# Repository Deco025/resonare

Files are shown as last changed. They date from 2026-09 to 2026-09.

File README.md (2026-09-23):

# Resonare

**120 W LCC-S 谐振式无线充电：发射板 + 接收板**





> *Resonare* (Latin: “to resound”) is an open-source 120 W wireless charger built on an LCC-S resonant
> topology. A 24 V transmitter drives a full bridge into an LCC compensation network; the receiver rectifies,
> steps down with a synchronous buck and charges a supercapacitor bank through an ideal-diode stage.
> Both boards are 4-layer KiCad 10 designs with complete fabrication outputs.

| 发射板 TX（82 × 60 mm） | 接收板 RX（75 × 60 mm） |
|---|---|
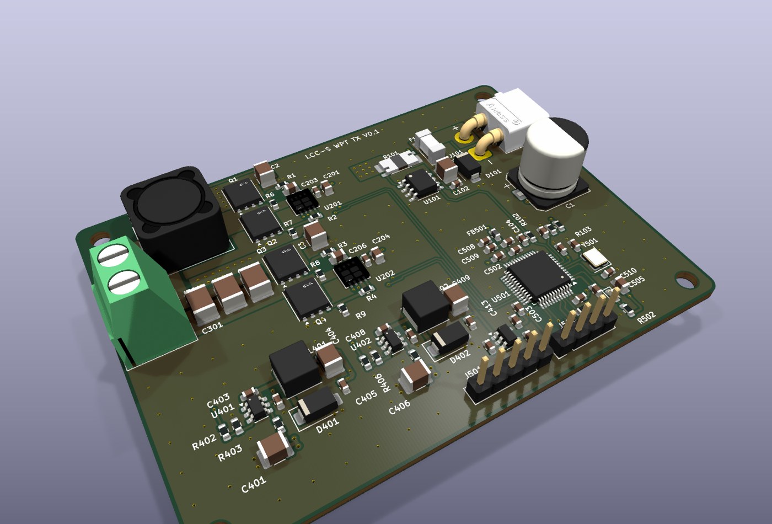
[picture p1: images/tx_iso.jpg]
TX
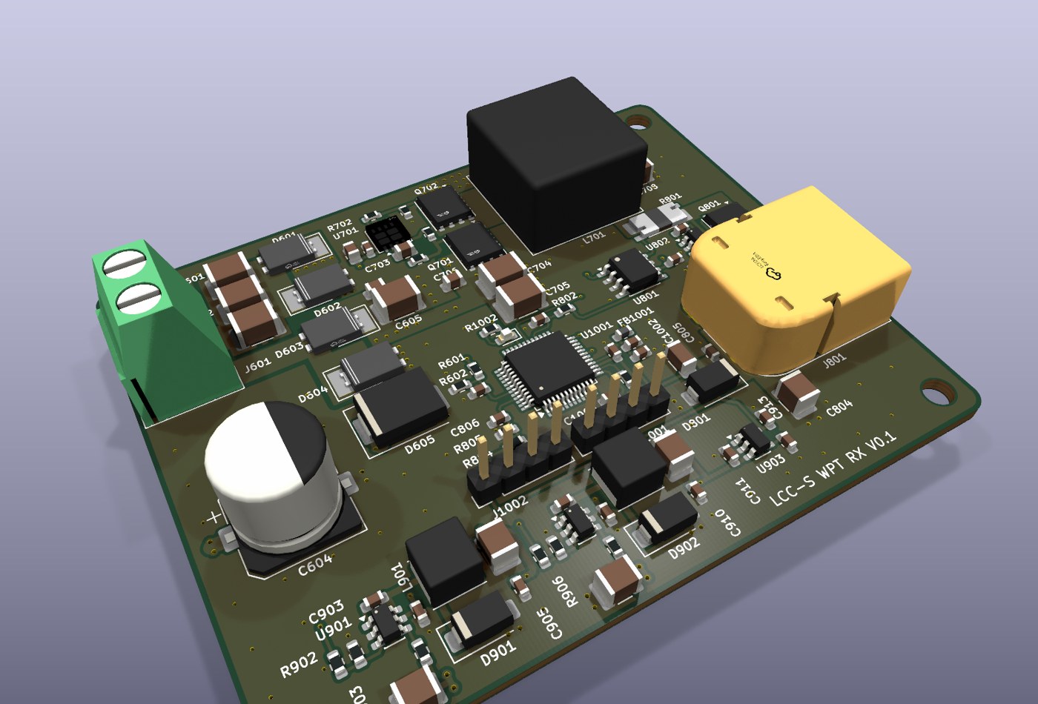
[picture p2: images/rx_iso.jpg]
RX
|  |  |

### PCB 走线

| | 顶层 F.Cu | 底层 B.Cu（从背面看） |
|---|---|---|
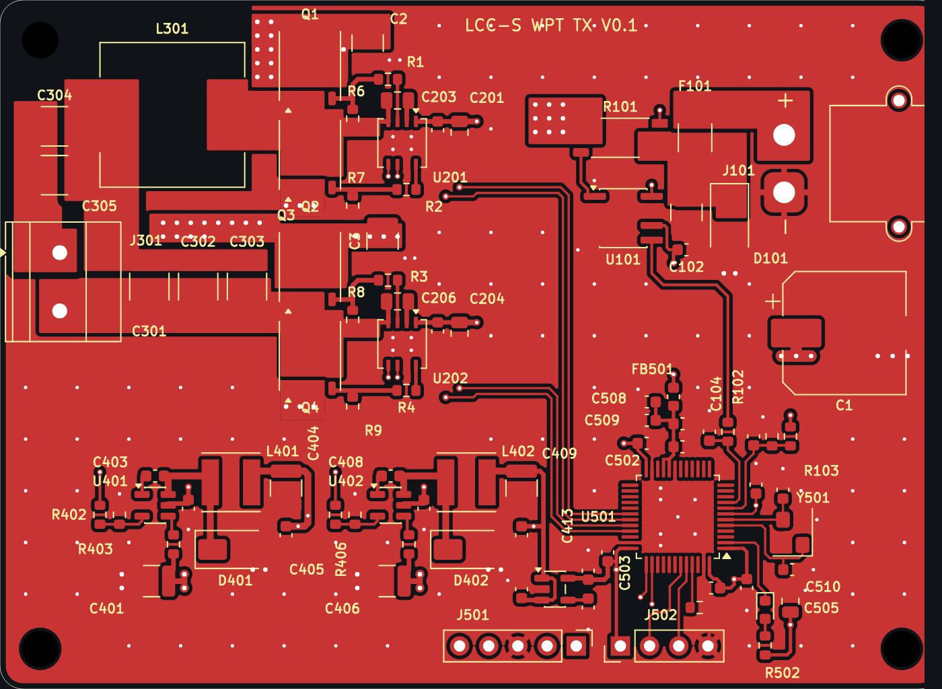
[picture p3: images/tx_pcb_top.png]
TX top copper
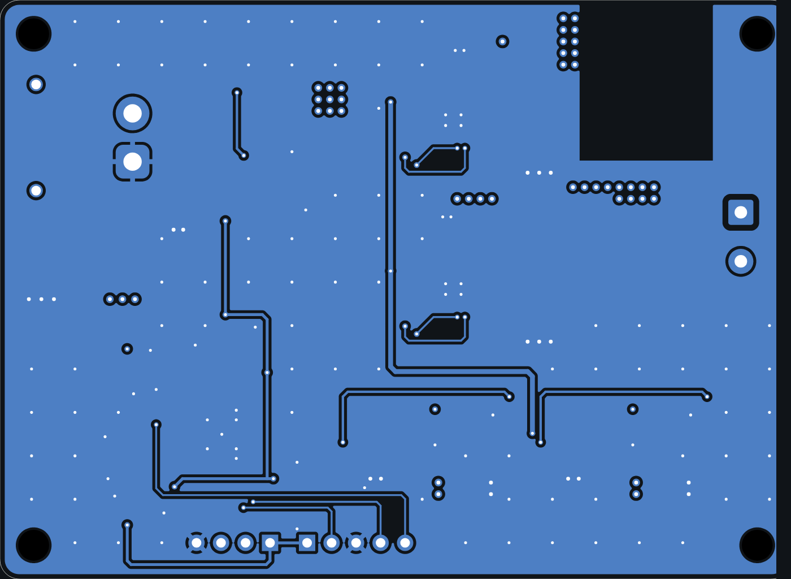
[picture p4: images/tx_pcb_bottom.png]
TX bottom copper
| **发射板 TX** |  |  |
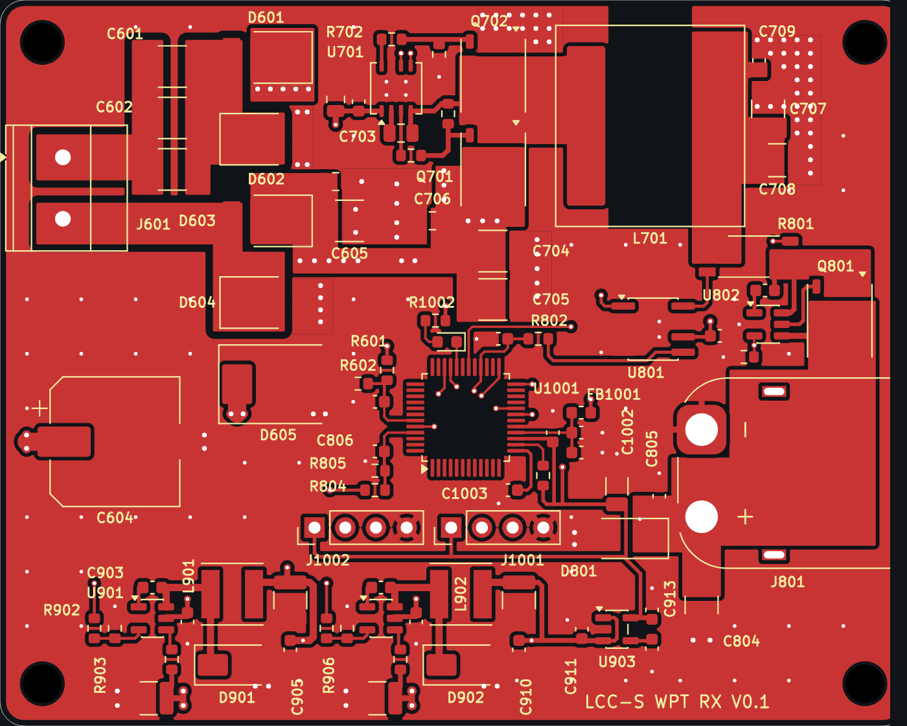
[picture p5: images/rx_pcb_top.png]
RX top copper
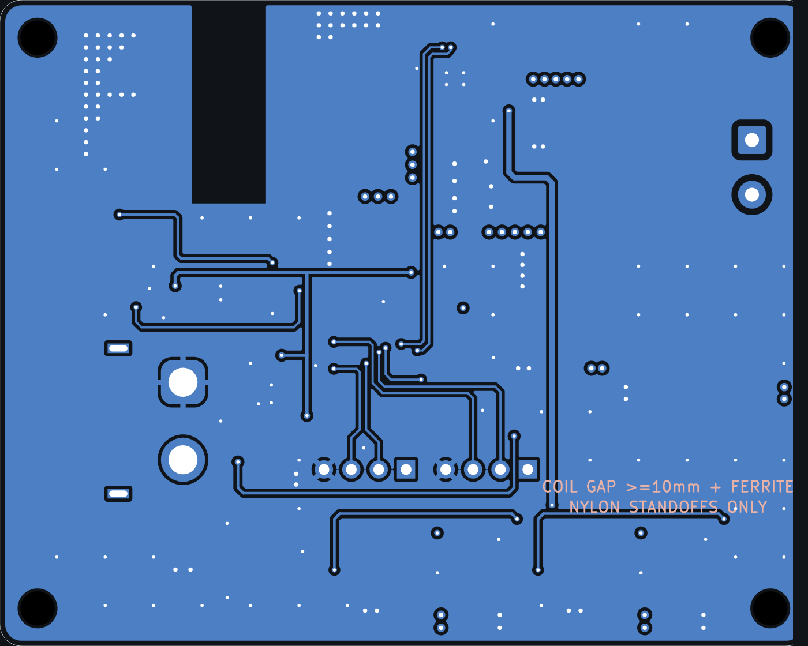
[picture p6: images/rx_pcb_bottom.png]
RX bottom copper
| **接收板 RX** |  |  |

第 2 层为整层地、第 3 层为整层电源（TX：VBUS；RX：VRECT），图中只画出两个外层。

---

## 目录

- [主要指标](#主要指标)
- [系统结构](#系统结构)
- [仓库结构](#仓库结构)
- [打开工程](#打开工程)
- [打样与装配](#打样与装配)
- [设计要点](#设计要点)
- [安全提示](#安全提示)
- [许可证](#许可证)
- [致谢](#致谢)

## 主要指标

| 项 | 值 |
|---|---|
| 发射端输入 | 24 V DC，XT30 接口，输入平均电流约 5.9 A（按 85 % 效率估算） |
| 输出功率 | 120 W 级（超级电容端） |
| 拓扑 | 全桥逆变 + LCC-S 补偿 |
| 逆变 / 谐振频率 | 144 kHz |
| 补偿参数 | Lf 6 µH；Lt = Lr 20 µH；Cf ≈ 203.6 nF，Ct ≈ 87.3 nF，Cr ≈ 61.1 nF（理想调谐） |
| 整流母线 VRECT | 标称 30 V |
| 接收端降压 | 同步 Buck，200 kHz，15 µH；充电电流上限 10 A（峰值约 11.2 A） |
| 负载 | 超级电容组，6–24 V，等效 10 F，XT60 接口 |
| 电流采样 | 2 mΩ 四端分流电阻 + INA240A2（×50）：10 A → 1.0 V |
| 主控 | TX：STM32G474CE（HRTIM 驱动全桥）；RX：STC32G12K128（PWM 驱动 Buck） |
| PCB | 4 层，1.6 mm，外层 2 oz / 内层 1 oz |

## 系统结构

```mermaid
flowchart LR
    subgraph TX [发射板]
        IN[24 V 输入<br/>保险丝 · TVS · 电流采样] --> FB[全桥<br/>4 × BSC070N10NS3G<br/>2 × UCC27211]
        FB --> LCC[LCC 补偿<br/>Lf · Cf · Ct]
        MCUT[STM32G474<br/>HRTIM · ADC · 比较器] --> FB
        AUXT[辅助电源<br/>24→12 V / 5 V / 3.3 V]
    end
    LCC -. 线圈 Lt ~ 磁耦合 ~ Lr .-> RECT
    subgraph RX [接收板]
        RECT[Cr + 全桥整流<br/>4 × SB2060L] --> BUCK[同步 Buck<br/>2 × BSC070N10NS3G<br/>UCC27211]
        BUCK --> OUT[电流采样 · 理想二极管<br/>LM74700 + N-MOS]
        OUT --> CAP[(超级电容组)]
        MCUR[STC32G12K128<br/>PWM · ADC · 比较器] --> BUCK
        AUXR[辅助电源<br/>VRECT→12 V / 5 V / 3.3 V]
    end
```

- 发射端过流保护：INA240 输出同时进 ADC 和片内比较器（COMP1），比较器直接触发 HRTIM 故障关断。
- 接收端过流保护：充电电流进 ADC 和片内比较器，比较器阈值用片内 1.19 V 基准，对应约 11.9 A。
- 防倒灌：同步 Buck 上管的体二极管会让超级电容反向放电到 VRECT，所以输出端串联 LM74700 + N-MOS 理想二极管，由 MCU 的 `CHG_EN` 控制。
- 接收端的辅助电源只从 VRECT 取电。小车离开发射线圈后，接收端 MCU 掉电，Buck 停止，理想二极管关断。
- 发射与接收的地完全隔离（`GND` / `GND_RX`）。

更完整的说明见 [docs/design.md](docs/design.md)。

## 仓库结构

```
.
├── p1_tx/                 发射板 KiCad 工程（原理图 + PCB）
│   └── fab/               发射板生产文件（Gerber zip、BOM、坐标、装配图、DRC 报告）
├── p1_rx/                 接收板 KiCad 工程
│   └── fab/               接收板生产文件
├── p1/                    整机原理图（发射与接收在同一个工程里，作系统参考）
│   └── 3dmodels/          第三方 3D 模型的来源清单（模型文件不随仓库分发）
├── docs/
│   ├── design.md          设计说明
│   └── schematics/        原理图 PDF（不装 KiCad 也能看）
├── images/                3D 渲染图
├── CHANGELOG.md
└── LICENSE                CERN-OHL-S-2.0
```

## 打开工程

1. 安装 [KiCad](https://www.kicad.org/) **10.0** 或更新版本。
2. 打开 `p1_tx/p1_tx.kicad_pro`（发射板）或 `p1_rx/p1_rx.kicad_pro`（接收板）。自定义符号在各工程自带的 `p1_parts.kicad_sym` 里；封装全部来自 KiCad 官方库。
3. **3D 模型（可选）**：有 9 种器件的 3D 模型不在 KiCad 官方库里，版权也不允许随仓库再分发。按 [p1/3dmodels/README.md](p1/3dmodels/README.md) 下载到 `p1/3dmodels/`，3D 查看器（`Alt+3`）里就能看到完整模型。不下载也不影响原理图、PCB 和生产文件。

## 打样与装配

生产文件已经导出好，坐标原点在板的左上角：

| | 发射板 | 接收板 |
|---|---|---|
| 上传给板厂 | [`p1_tx/fab/p1_tx-gerber.zip`](p1_tx/fab/p1_tx-gerber.zip) | [`p1_rx/fab/p1_rx-gerber.zip`](p1_rx/fab/p1_rx-gerber.zip) |
| 物料清单 | [`p1_tx-bom.csv`](p1_tx/fab/p1_tx-bom.csv) | [`p1_rx-bom.csv`](p1_rx/fab/p1_rx-bom.csv) |
| 贴片坐标 | [`p1_tx-pos.csv`](p1_tx/fab/p1_tx-pos.csv) | [`p1_rx-pos.csv`](p1_rx/fab/p1_rx-pos.csv) |
| 装配图 | [`p1_tx-assembly.pdf`](p1_tx/fab/p1_tx-assembly.pdf) | [`p1_rx-assembly.pdf`](p1_rx/fab/p1_rx-assembly.pdf) |
| 下单参数 | [`p1_tx/fab/README.md`](p1_tx/fab/README.md) | [`p1_rx/fab/README.md`](p1_rx/fab/README.md) |

下单要点：

- 4 层，1.6 mm FR4，外层 2 oz、内层 1 oz，无铅喷锡，过孔盖油。
- 叠层顺序：F.Cu / In1（地）/ In2（电源：TX 为 VBUS，RX 为 VRECT）/ B.Cu。**内层顺序不能调换**。
- 最小线宽 / 线距 0.2 / 0.2 mm，最小过孔 0.5 / 0.3 mm（焊环 0.1 mm）。外层 2 oz 下请对照板厂工艺能力确认。
- 接收板有 2 个 0.6 × 1.7 mm 金属化槽孔。
- 线圈（L302、L601）在板外，BOM 里的线圈条目不贴装。安装孔 H1–H4 为 M3。
- 为了版面整洁，丝印上放不下的一些小阻容位号只保留在装配层（F.Fab），焊接时请对照装配图。

DRC 里保留了几条已接受的丝印告警：驱动器封装的 1 脚标记压在自举电容焊盘上 0.05–0.14 mm；接线端子外框到达板边。这两种情况板厂都会自动裁掉焊盘上和板外的丝印。

## 设计要点

- **栅极回路最小化**：半桥驱动器夹在上下管的栅极之间，LO / VSS 对着下管，HO 从自举电容两焊盘之间穿出，栅极电阻紧贴 MOS。
- **完整的回流平面**：第 2 层整层是地，第 3 层整层是电源。高 di/dt 的信号都走在顶层，紧贴地平面；底层贴着电源平面，只走慢信号和跨越线。
- **开尔文采样**：四端分流电阻的检测端单独引线，成对走到 INA240；ADC 的 RC 滤波放在 MCU 引脚旁。
- **功率铺铜**：开关节点铺铜面积受控，输入去耦电容紧贴 MOS 管；两面地铺铜，用缝合过孔连到地平面。
- **LCC 电感下方挖空内层**：发射端 Lf 流过全部逆变电流，其下方的内层平面挖空，避免涡流发热。接收端 Buck 电感只有纹波电流，下方平面保留，起屏蔽作用。

详见 [docs/design.md](docs/design.md)。

## 安全提示

- 谐振网络（Cf、Ct、Cr、线圈）上的电压可以远高于直流母线电压，通电时不要触碰。
- 超级电容组储能大、短路电流大：接线前先确认极性（XT60：焊盘 1 为负、焊盘 2 为正），调试时加限流。
- 首次上电请用限流电源，按“辅助电源 → MCU → 驱动 → 小功率 → 满功率”逐级进行。
- 线圈之间留足间隙，使用尼龙柱安装（接收板背面丝印有提示）。

## 许可证

本项目的硬件设计文件（原理图、PCB、生产文件、文档）采用
**[CERN Open Hardware Licence Version 2 – Strongly Reciprocal (CERN-OHL-S-2.0)](LICENSE)**。

简单说：可以自由使用、学习、修改、生产和销售；但如果你发布修改后的设计，或者销售基于它的产品，必须用同样的许可证公开对应的设计源文件。

第三方封装、符号和 3D 模型各自遵循其原始许可，不在本许可证范围内。

## 致谢

- [KiCad](https://www.kicad.org/) 及其官方符号 / 封装 / 3D 库。
- 器件 3D 模型的来源见 [p1/3dmodels/SOURCES.md](p1/3dmodels/SOURCES.md)。

欢迎通过 Issue 反馈问题或提出改进。

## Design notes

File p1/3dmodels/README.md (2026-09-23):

# 3D 模型

下面 9 种器件的 3D 模型不在 KiCad 官方 3D 库里。它们来自厂家或立创商城，版权归原作者，所以**不随本仓库分发**。

只看原理图、PCB 或出生产文件时，不需要这些模型。想在 3D 查看器里看到完整外观，就按下表下载，**改成表中的文件名**，放进本目录（`p1/3dmodels/`）。两块板的封装已经指向这里，对齐参数也已设好。

| 文件名 | 器件 | 位号 | 来源 |
|---|---|---|---|
| `BSC070N10NS3G.step` | Infineon BSC070N10NS3G（PG-TDSON-8） | TX：Q1–Q4；RX：Q701、Q702、Q801 | 立创 C501502 |
| `UCC27211DRM.step` | TI UCC27211DRMR（VSON-8，4 × 4 mm） | TX：U201、U202；RX：U701 | 立创 C544677 |
| `SB2060L_PowerDI-5.step` | SB2060L（取得的模型为 TO-277 外形，作 PowerDI-5 替身） | RX：D601–D604 | 立创 C6067491 |
| `L_12x12mm_H8mm.step` | 12 × 12 mm 功率电感（TDK B82477P4 系列外形） | TX：L301 | 立创 C2042433 |
| `Vishay_WSK2512.step` | Vishay WSK2512 四端分流电阻 | TX：R101；RX：R801 | Vishay 官网 |
| `Littelfuse_NANO2_451_453.step` | Littelfuse NANO2 451 / 453 保险丝 | TX：F101 | pcb-3d.com |
| `AMASS_XT30PW-M.step` | AMASS XT30PW-M | TX：J101 | 立创 C431092 |
| `AMASS_XT60PW-M.step` | AMASS XT60PW-M | RX：J801 | 立创 C98732 |

- 立创的模型：在立创商城打开对应料号页面，从 EasyEDA 的 3D 模型处导出 STEP。也可以用开源工具 [easyeda2kicad](https://github.com/uPesy/easyeda2kicad.py)，例如：`easyeda2kicad --3d --lcsc_id C501502`。
- 完整链接与许可说明见 [SOURCES.md](SOURCES.md)。
- NR5040 电感（TX：L401、L402；RX：L901、L902）用的是 KiCad 自带的同尺寸模型 `L_APV_ANR5040`，无需下载。

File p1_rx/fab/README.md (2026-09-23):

# p1_rx 生产文件（接收板 RX）

由 `kicad-cli` 从 `p1_rx.kicad_pcb` 导出，坐标原点 = 板左上角（钻孔/贴片原点）。

## 下单参数

| 项 | 值 |
|---|---|
| 层数 | 4 层 |
| 板厚 | 1.6 mm，FR4 |
| 铜厚 | 外层 2 oz（70 µm），内层 1 oz（35 µm） |
| 叠层 | F.Cu / 0.2 PP / In1（GND_RX 整层）/ 0.97 芯板 / In2（VRECT 整层）/ 0.2 PP / B.Cu，**内层顺序不要调换** |
| 尺寸 | 75 × 60 mm |
| 表面处理 | 无铅喷锡（HASL lead-free） |
| 阻焊 / 丝印 | 绿油 / 白字 |
| 过孔 | 盖油（丝印有少量印在过孔上） |
| 最小线宽 / 间距 | 0.2 / 0.2 mm |
| 过孔（外径/孔径） | 0.5/0.3（18 个）、0.6/0.3（85 个）、0.8/0.4（104 个）；最小焊环 0.1 mm |
| 焊盘孔 | PTH 1.0 / 1.3 / 2.7 mm，NPTH 3.2 mm（4 个安装孔） |
| 槽孔 | 2 个 0.6 × 1.7 mm 金属化槽孔（钻孔文件里按槽孔输出） |

外层 2 oz 下的 0.2 / 0.2 mm 线宽线距、0.1 mm 焊环，下单前请对照所选板厂的工艺能力确认。

## 文件

- `p1_rx-gerber.zip`：上传用，含 11 层 Gerber（X2）、PTH/NPTH 分开的 Excellon 钻孔、`.gbrjob`。
- `gerber/`：同上的散文件，另有钻孔分布图 PDF。
- `p1_rx-bom.csv`：按 值 + 耐压 + 封装 合并。线圈模型（L302/L601）不在板上、安装孔 H1–H4 不贴装。
- `p1_rx-pos.csv`：贴片坐标（mm，y 向上为正的 KiCad 惯例，原点在板左上角，全部为顶面）。若用嘉立创 SMT，需要按其模板改列名并补 LCSC 料号。
- `p1_rx-assembly.pdf`：装配图（F.Fab 层，含丝印上放不下而隐藏的 29 个小阻容位号）。
- `p1_rx-drc.rpt`：DRC 报告：0 错误、0 未连接；剩下的都是已接受的丝印项（驱动器 1 脚三角压自举电容焊盘 0.05–0.14 mm、接线端子外框到板边），板厂会自动裁掉焊盘上和板外的丝印。

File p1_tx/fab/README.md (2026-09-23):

# p1_tx 生产文件（发射板 TX）

由 `kicad-cli` 从 `p1_tx.kicad_pcb` 导出，坐标原点 = 板左上角（钻孔/贴片原点）。

## 下单参数

| 项 | 值 |
|---|---|
| 层数 | 4 层 |
| 板厚 | 1.6 mm，FR4 |
| 铜厚 | 外层 2 oz（70 µm），内层 1 oz（35 µm） |
| 叠层 | F.Cu / 0.2 PP / In1（GND 整层）/ 0.97 芯板 / In2（VBUS 整层）/ 0.2 PP / B.Cu，**内层顺序不要调换** |
| 尺寸 | 82 × 60 mm |
| 表面处理 | 无铅喷锡（HASL lead-free） |
| 阻焊 / 丝印 | 绿油 / 白字 |
| 过孔 | 盖油（丝印有少量印在过孔上） |
| 最小线宽 / 间距 | 0.2 / 0.2 mm |
| 过孔（外径/孔径） | 0.5/0.3（13 个）、0.6/0.3（136 个）、0.8/0.4（62 个）；最小焊环 0.1 mm |
| 焊盘孔 | PTH 1.0 / 1.3 / 1.9 mm，NPTH 3.2 mm（4 个安装孔） |
| 槽孔 | 无 |

外层 2 oz 下的 0.2 / 0.2 mm 线宽线距、0.1 mm 焊环，下单前请对照所选板厂的工艺能力确认。

## 文件

- `p1_tx-gerber.zip`：上传用，含 11 层 Gerber（X2）、PTH/NPTH 分开的 Excellon 钻孔、`.gbrjob`。
- `gerber/`：同上的散文件，另有钻孔分布图 PDF。
- `p1_tx-bom.csv`：按 值 + 耐压 + 封装 合并。线圈模型（L302/L601）不在板上、安装孔 H1–H4 不贴装。
- `p1_tx-pos.csv`：贴片坐标（mm，y 向上为正的 KiCad 惯例，原点在板左上角，全部为顶面）。若用嘉立创 SMT，需要按其模板改列名并补 LCSC 料号。
- `p1_tx-assembly.pdf`：装配图（F.Fab 层，含丝印上放不下而隐藏的 22 个小阻容位号）。
- `p1_tx-drc.rpt`：DRC 报告：0 错误、0 未连接；剩下的都是已接受的丝印项（驱动器 1 脚三角压自举电容焊盘 0.05–0.14 mm、接线端子外框到板边），板厂会自动裁掉焊盘上和板外的丝印。

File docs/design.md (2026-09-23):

# Resonare 设计说明

本文记录 v0.1 的设计依据与取舍。

## 1. 能量链

```
24 V DC ─ TX 输入（保险丝、TVS、2 mΩ 分流 + INA240）─ VBUS ─ 全桥 Q1–Q4 ─ SWA / SWB ─ LCC（Lf、Cf、Ct、Lt）
        ~~ 磁耦合 ~~
Lr、Cr ─ 全桥整流 D601–D604 ─ VRECT ─ 同步 Buck ─ BUCK_OUT ─ 分流采样 ─ 理想二极管 ─ VSCAP ─ 超级电容组
```

发射端地为 `GND`，接收端地为 `GND_RX`，两者完全隔离。

## 2. 主要参数

| 项 | 值 |
|---|---|
| 直流输入 | 24 V；120 W 级；输入平均电流约 5.9 A（按 85 % 效率） |
| 逆变 / 谐振频率 | 144 kHz |
| LCC-S | Lf 6 µH，Lt = Lr 20 µH；Cf ≈ 203.6 nF，Ct ≈ 87.3 nF，Cr ≈ 61.1 nF（理想调谐公式） |
| 整流母线 | 标称 30 V |
| Buck | 200 kHz，15 µH；充电电流上限 10 A；峰值约 11.2 A |
| 超级电容 | 6–24 V，等效 10 F；电容端最高 120 W |
| 采样 | 2 mΩ 分流 + INA240A2（×50）：10 A → 1.0 V |

## 3. 发射板（TX）

| 功能块 | 主要器件 | 说明 |
|---|---|---|
| 输入 | J101（XT30）、F101（10 A）、D101（TVS）、R101 + U101（INA240A2） | 输入电流经 INA240 送 MCU 的 ADC 与 COMP1（PA1），比较器直接触发 HRTIM 故障关断 |
| 全桥 | Q1–Q4 BSC070N10NS3G（100 V） | 桥臂中点 SWA / SWB 用顶层铺铜，面积受控 |
| 驱动 | U201 / U202 UCC27211 | 内置自举二极管；自举电容 220 nF；VDD 去耦 2.2 µF + 100 nF |
| LCC 网络 | L301（Lf）、C301–C305（Cf / Ct，C0G / 薄膜） | 发射线圈 L302 在板外，经 J301 接入 |
| 辅助电源 | U401 / U402 LMR16006（24 → 12 V / 5 V）、U403 TC2185（5 → 3.3 V） | 12 V 供驱动，3.3 V 供 MCU |
| 主控 | U501 STM32G474CE | HRTIM 产生 4 路 PWM；ADC 采样 VBUS 与输入电流；SWD（J501）、UART（J502） |

## 4. 接收板（RX）

| 功能块 | 主要器件 | 说明 |
|---|---|---|
| 线圈与整流 | J601、C601–C603（Cr）、D601–D604 SB2060L | 接收线圈 L601 在板外 |
| VRECT | C604（100 µF）、C605 / C704 / C705、D605（TVS） | Buck 输入最坏按 TVS 钳位约 53 V 计，100 V MOS 留有余量 |
| 同步 Buck | Q701 / Q702 BSC070N10NS3G、U701 UCC27211、L701 15 µH | 200 kHz |
| 输出 | R801 + U801（INA240A2）、U802 LM74700 + Q801、J801（XT60） | 理想二极管防止超级电容经上管体二极管倒灌到 VRECT，EN 由 MCU `CHG_EN` 控制 |
| 辅助电源 | U901 / U902 LMR16006（VRECT → 12 V / 5 V）、U903 TC2185（5 → 3.3 V） | 只从 VRECT 取电：离开发射线圈后接收端自动断电 |
| 主控 | U1001 STC32G12K128（LQFP-48） | PWM 互补驱动 Buck；ADC 采 VRECT、VSCAP、充电电流；充电电流同时进片内比较器（CMP+，负端用 1.19 V 内部基准，约 11.9 A 动作）；ISP（J1001）、UART（J1002） |

反馈通道（ASK 或无线串口）尚未确定，两端 MCU 都预留了 UART 排针。超级电容串联均衡放在电容组一侧，本板不做。

接插件极性：XT30 / XT60 封装的焊盘 1 为负、焊盘 2 为正。

## 5. PCB

### 5.1 叠层

| 层 | 用途 | 铜厚 |
|---|---|---|
| F.Cu | 元件、功率铺铜、关键信号 | 2 oz |
| In1.Cu | 地平面（整层） | 1 oz |
| In2.Cu | 电源平面（TX：VBUS；RX：VRECT） | 1 oz |
| B.Cu | 慢信号、跨越线、地铺铜 | 2 oz |

板厚 1.6 mm；外层与内层之间为 0.2 mm 半固化片，中间为 0.97 mm 芯板。

### 5.2 布局与布线原则

1. **先看回路面积。** 每个栅极回路和去耦回路都先估算面积，再定器件朝向和走线。半桥驱动器转向夹在上下管的栅极之间：LO / VSS 对着下管，HO 从自举电容两焊盘之间穿出，栅极电阻紧贴 MOS 管；两路桥臂几何完全相同。
2. **清楚回流在哪一层。** 顶层紧贴地平面，高 di/dt 信号（栅极驱动、开关节点、采样）都放在顶层。底层贴着电源平面，只走慢信号和必要的跨越线。
3. **几何规范。** 正交走线 + 45° 倒角，不用锐角和长斜线；T 形连接成 90°；沿焊盘轴线进出。成组的相关网络平行、等距。
4. **开尔文采样。** 四端分流电阻的检测端单独引线、成对走线；接收端的负端检测线走在分流电阻本体下方，并与正端线上下重叠一段，采样环路尽量小。ADC 的 RC 滤波放在 MCU 引脚旁。
5. **功率级。** 开关节点铺铜只覆盖必要面积；输入去耦电容紧贴 MOS 管；地焊盘用铺铜岛并打过孔连到地平面。
6. **磁性元件下方。** 发射端 Lf（L301）流过全部逆变电流，其下方 In1 / In2 挖空，避免平面涡流发热。接收端 Buck 电感 L701 只有纹波电流，下方内层保留，起屏蔽作用；外层地铺铜在两个电感本体下方都留空。
7. **地铺铜与缝合孔。** 两个外层都铺地（通孔焊盘用热焊盘、贴片焊盘实连），缝合过孔按 4.5 mm 网格只放在两面都有地、且不在任何元件本体下方的空地上。

### 5.3 已知取舍

- 接收端 Buck 的两路 PWM 从 MCU 到驱动器有约 27 mm 走在底层（参考层为 VRECT 平面）。原因是若走顶层，就要切断 VRECT 输入铺铜带、并挪开 LED 和 C706。两根线并排紧贴，两端都有 VRECT–地去耦电容，供回流换层。
- 驱动器封装的 1 脚丝印标记与自举电容焊盘重叠 0.05–0.14 mm，保持官方封装原样，由板厂裁掉焊盘上的丝印。
- 部分小阻容的位号在丝印上放不下，只保留在装配层，焊接时请对照装配图。

## 6. 关键器件选型与余量

母线工作电压 24 V。选型按 120 W 满载应力，并给开关尖峰和热插拔浪涌留出余量。

| 器件 | 选型 | 120 W 下的应力 | 余量 / 依据 |
|---|---|---|---|
| Q1–Q4、Q701、Q702、Q801 | BSC070N10NS3G（100 V / 7 mΩ） | TX 母线 24 V，TVS 钳位后约 45 V；RX 母线 30 V，钳位后约 53 V | 耐压约为钳位电压的 2 倍 |
| F101 | 10 A 慢断（NANO2 453） | 输入最大约 5.9 A | 约 1.7 倍；慢断可承受上电时给 C1 充电的冲击电流 |
| D101 | SMAJ28A | 工作电压 24 V | 最高工作电压 28 V，大于 24 V + 15 %；钳位约 45 V，低于 LMR16006 的 60 V |
| D605 | SMCJ33A | VRECT 标称 30 V | 最高工作电压 33 V；钳位约 53 V，低于 SB2060L 的 60 V 和 MOS 管的 100 V |
| D601–D604 | SB2060L（20 A / 60 V） | 输出约 4.2 A，两管串联导通损耗约 4.2 W | 电流、耐压均有充足余量 |
| C301–C303（Cf = 203 nF） | 250 V C0G 1812 ×3 | 约 37 V rms / 7 A rms | 峰值约 52 V，耐压余量 4 倍以上；电流由三颗并联分担 |
| C304–C305（Ct = 87.6 nF） | 250 V C0G 1812 ×2 | 约 50 V rms / 4 A rms | 峰值约 71 V，耐压余量约 3.5 倍 |
| C601–C603（Cr = 61.2 nF） | 250 V C0G 1812 ×3 | 约 85 V rms / 4.7 A rms | 峰值约 120 V，耐压余量约 2 倍 |
| C2、C3 | 4.7 µF / 50 V X7R 1210（每个桥臂一颗） | 桥臂纹波约 2.4 A rms（2 × fsw） | 50 V 覆盖母线与 45 V 钳位 |
| C1 | 220 µF / 50 V 电解 | 低频储能 | 50 V 覆盖母线与钳位 |
| C604、C605、C704、C705 | 100 µF / 63 V 电解，10 µF / 63 V X7R 1812 | VRECT 30 V，钳位约 53 V | 63 V 覆盖钳位电压 |

- 防反接：输入端用的 XT30 有防呆，插反在机械上就不可能，所以不另加防反接 MOS。
- 谐振电容取值：按线圈实测的 Lf、Lt、Lr 微调，并联的小电容（C303、C305、C602、C603）用于修调。

## 7. 建议的调试顺序

1. 目检与短路检查：各电源轨对地电阻，重点是 VBUS、VRECT、12 V、5 V、3.3 V。
2. 限流电源单独给辅助电源供电，确认 12 V / 5 V / 3.3 V。
3. 下载程序，确认 PWM 波形、死区和故障关断（先不接功率级电源）。
4. 驱动器输出接 MOS 管，低压（如 5 V）检查开关节点波形和栅极振铃。
5. 小功率谐振：低母线电压下测量线圈电流、谐振频率，按实测 Lt / Lr 修正 Cf、Ct、Cr。
6. 接收端空载与轻载：检查 VRECT、Buck 输出、理想二极管和充电电流采样。
7. 逐步升到满功率，同时监测温升（MOS 管、Lf、整流二极管、分流电阻）。

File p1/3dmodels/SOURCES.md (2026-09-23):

# 3D STEP 模型来源

| 文件名 | 料号 / 外形 | 来源 URL | LCSC 编号 | 下载日期 | 许可说明 |
|---|---|---|---|---|---|
| `BSC070N10NS3G.step` | Infineon BSC070N10NS3G，PG-TDSON-8 | https://www.lcsc.com/product-detail/MOSFETs_Infineon-Technologies-BSC070N10NS3G_C501502.html（EasyEDA STEP） | C501502 | 2026-09-23 | 来源页未注明 |
| `UCC27211DRM.step` | TI UCC27211DRMR，VSON-8-EP 4×4 mm | https://www.lcsc.com/product-detail/gate-drivers_texas-instruments-ucc27211drmr_C544677.html（EasyEDA STEP） | C544677 | 2026-09-23 | 来源页未注明 |
| `SB2060L_PowerDI-5.step` | GOODWORK SB2060L；取得的模型标为 TO-277-3 | https://item.szlcsc.com/7007015.html（EasyEDA STEP） | C6067491 | 2026-09-23 | 来源页未注明 |
| `L_12x12mm_H8mm.step` | TDK B82477P4682M000，6.8 µH，模型尺寸 12.5×12.5×8.5 mm | https://www.lcsc.com/it/product-detail/C2042433.html（EasyEDA STEP） | C2042433 | 2026-09-23 | 来源页未注明 |
| `Vishay_WSK2512.step` | Vishay WSK2512，0.001–0.0049 Ω 模型范围，包含 2 mΩ | https://www.vishay.com/docs/30323/_wsk2512_3dmodel.zip | C3997408（2 mΩ 料号） | 2026-09-23 | “free of charge for your use”; “remains the sole property of Vishay Intertechnology, Inc. or Ultra Librarian/EMA Design Automation, Inc.” |
| `Littelfuse_NANO2_451_453.step` | Littelfuse NANO2 0451/0453 系列 STEP 外形 | https://www.pcb-3d.com/wordpress/models/fuse_littelfuse_451-453_xxx_series_nano_sm/ | C178995（0453010.MR，10 A） | 2026-09-23 | 来源页未注明 |
| `AMASS_XT30PW-M.step` | XT30PW-M 外形候选；模型来源料号 XT30PW-M30.G.Y（15 A） | https://www.lcsc.com/product-detail/plug_Changzhou-Amass-Elec-XT30PW-M_C431092.html（EasyEDA STEP） | C42039231（XT30PW-M）；模型取自 C431092 | 2026-09-23 | 来源页未注明 |
| `AMASS_XT60PW-M.step` | AMASS XT60PW-M 卧式公头 | https://www.lcsc.com/product-detail/plug_changzhou-amass-elec-xt60pw-m_C98732.html（EasyEDA STEP） | C98732 | 2026-09-23 | 来源页未注明 |

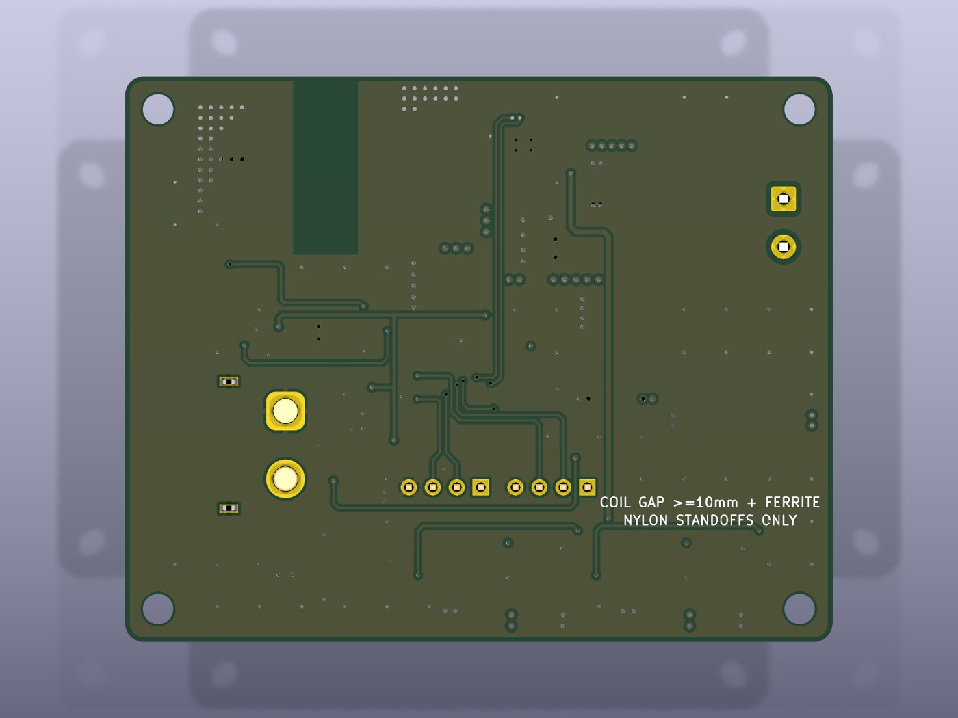
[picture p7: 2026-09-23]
images/rx_bottom.jpg

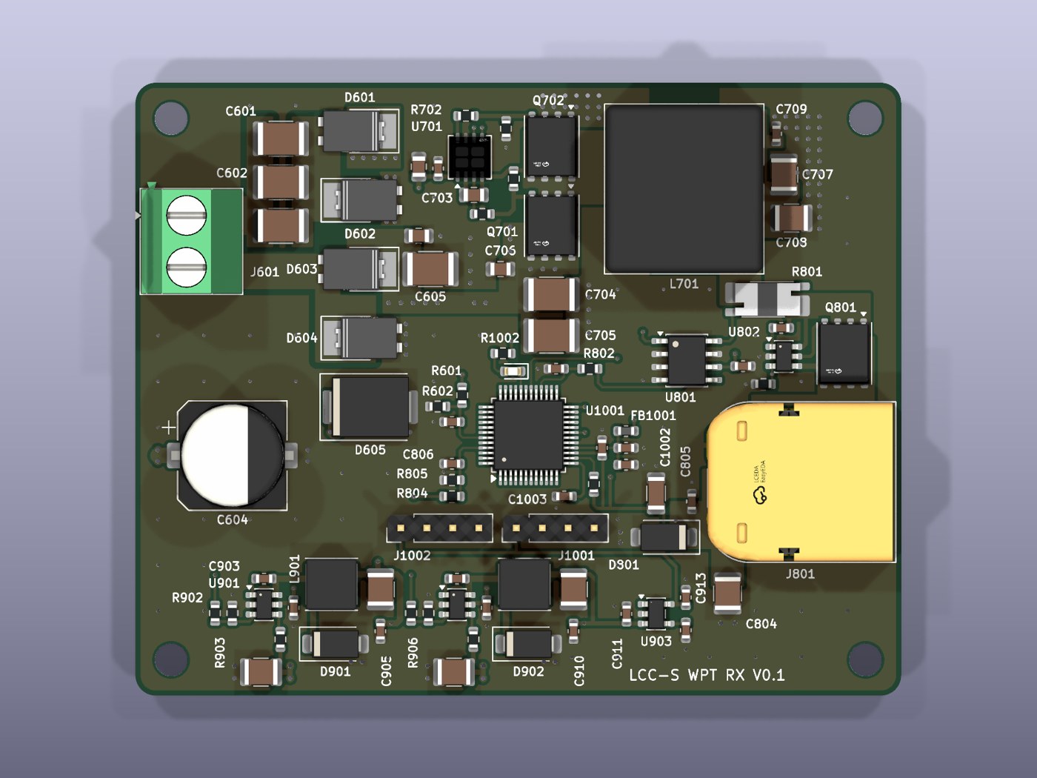
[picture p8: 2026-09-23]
images/rx_top.jpg

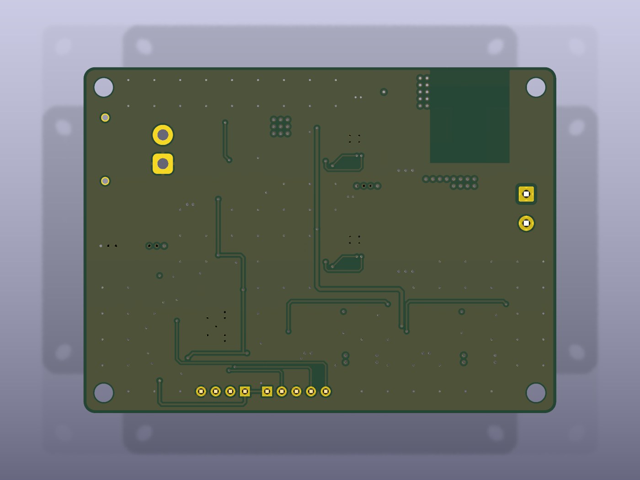
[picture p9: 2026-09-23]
images/tx_bottom.jpg

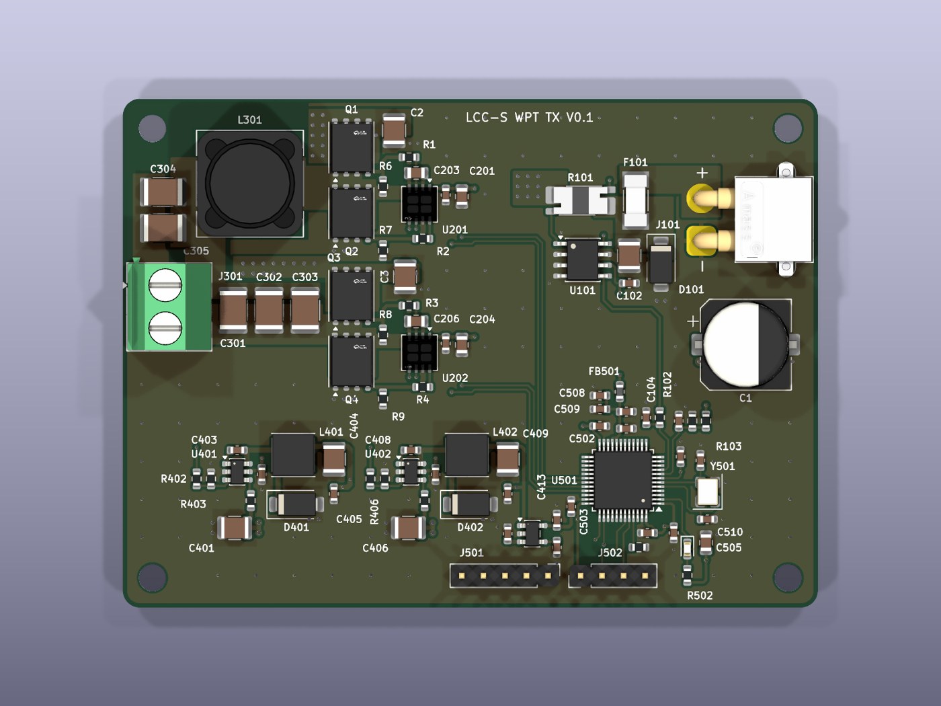
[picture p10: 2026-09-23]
images/tx_top.jpg

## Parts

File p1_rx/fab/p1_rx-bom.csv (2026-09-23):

Refs | Value | Voltage | Footprint | Qty | DNP
C601 | 56nF | 250V C0G | Capacitor_SMD:C_1812_4532Metric | 1
C602 | 4.7nF | 250V C0G | Capacitor_SMD:C_1812_4532Metric | 1
C603 | 470pF | 250V C0G | Capacitor_SMD:C_1812_4532Metric | 1
C604 | 100uF | 63V | Capacitor_SMD:CP_Elec_10x10.5 | 1
C605,C704,C705 | 10uF | 63V | Capacitor_SMD:C_1812_4532Metric | 3
C606,C706 | 100nF | 100V | Capacitor_SMD:C_0805_2012Metric | 2
C607,C702,C709,C801,C803,C805,C806,C903,C905,C908,C910,C1001,C1003,C1005 | 100nF |  | Capacitor_SMD:C_0603_1608Metric | 14
C701 | 2.2uF | 25V | Capacitor_SMD:C_0805_2012Metric | 1
C703 | 220nF | 50V | Capacitor_SMD:C_0805_2012Metric | 1
C707,C708 | 22uF | 35V | Capacitor_SMD:C_1210_3225Metric | 2
C802 | 1nF |  | Capacitor_SMD:C_0603_1608Metric | 1
C804 | 22uF |  | Capacitor_SMD:C_1210_3225Metric | 1
C901,C906 | 4.7uF | 100V | Capacitor_SMD:C_1210_3225Metric | 2
C902,C907 | 100nF | 100V | Capacitor_SMD:C_0603_1608Metric | 2
C904 | 22uF | 25V | Capacitor_SMD:C_1210_3225Metric | 1
C909 | 22uF | 16V | Capacitor_SMD:C_1210_3225Metric | 1
C911,C913,C1004 | 1uF |  | Capacitor_SMD:C_0603_1608Metric | 3
C912 | 10nF |  | Capacitor_SMD:C_0603_1608Metric | 1
C1002 | 22uF | 16V | Capacitor_SMD:C_1206_3216Metric | 1
D601,D602,D603,D604 | SB2060L |  | Diode_SMD:D_PowerDI-5 | 4
D605 | SMCJ33A |  | Diode_SMD:D_SMC | 1
D801 | SMAJ26A |  | Diode_SMD:D_SMA | 1
D901,D902 | SS110 |  | Diode_SMD:D_SMA | 2
D1001 | LED_G |  | LED_SMD:LED_0603_1608Metric | 1
FB1001 | 600R@100MHz |  | Inductor_SMD:L_0603_1608Metric | 1
J601 | RX_COIL |  | TerminalBlock_Phoenix:TerminalBlock_Phoenix_MKDS-1,5-2-5.08_1x02_P5.08mm_Horizontal | 1
J801 | XT60_SUPERCAP |  | Connector_AMASS:AMASS_XT60PW-M_1x02_P7.20mm_Horizontal | 1
J1001 | ISP |  | Connector_PinHeader_2.54mm:PinHeader_1x04_P2.54mm_Vertical | 1
J1002 | UART_LINK |  | Connector_PinHeader_2.54mm:PinHeader_1x04_P2.54mm_Vertical | 1
L601 | 20uH |  |  | 1
L701 | 15uH |  | Inductor_SMD:L_Coilcraft_XAL1510-153 | 1
L901 | 56uH |  | Inductor_SMD:L_Taiyo-Yuden_NR-50xx | 1
L902 | 33uH |  | Inductor_SMD:L_Taiyo-Yuden_NR-50xx | 1
Q701,Q702,Q801 | BSC070N10NS3G |  | Package_SON:Infineon_PG-TDSON-8_6.15x5.15mm | 3
R601,R804 | 150k |  | Resistor_SMD:R_0603_1608Metric | 2
R602,R703,R704,R805,R903,R906,R1001 | 10k |  | Resistor_SMD:R_0603_1608Metric | 7
R701,R702 | 10R |  | Resistor_SMD:R_0603_1608Metric | 2
R801 | 2m |  | Resistor_SMD:R_Shunt_Vishay_WSK2512_6332Metric_T1.19mm | 1
R802 | 100 |  | Resistor_SMD:R_0603_1608Metric | 1
R803,R901,R904 | 100k |  | Resistor_SMD:R_0603_1608Metric | 3
R902 | 147k |  | Resistor_SMD:R_0603_1608Metric | 1
R905 | 54.9k |  | Resistor_SMD:R_0603_1608Metric | 1
R1002 | 1k |  | Resistor_SMD:R_0603_1608Metric | 1
U701 | UCC27211 |  | Package_SON:HVSON-8-1EP_4x4mm_P0.8mm_EP2.2x3.1mm | 1
U801 | INA240A2D |  | Package_SO:SOIC-8_3.9x4.9mm_P1.27mm | 1
U802 | LM74700 |  | Package_TO_SOT_SMD:SOT-23-6 | 1
U901,U902 | LMR16006X |  | Package_TO_SOT_SMD:SOT-23-6 | 2
U903 | TC2185-3.3 |  | Package_TO_SOT_SMD:SOT-23-5 | 1
U1001 | STC32G12K128 |  | Package_QFP:LQFP-48_7x7mm_P0.5mm | 1

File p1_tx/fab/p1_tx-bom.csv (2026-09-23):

Refs | Value | Voltage | Footprint | Qty | DNP
C1 | 220uF | 50V | Capacitor_SMD:CP_Elec_10x10.5 | 1
C2,C3 | 4.7uF | 50V | Capacitor_SMD:C_1210_3225Metric | 2
C101,C401,C406 | 10uF | 50V | Capacitor_SMD:C_1210_3225Metric | 3
C102,C105,C202,C205,C402,C403,C405,C407,C408,C410,C501,C502,C503,C504,C512 | 100nF |  | Capacitor_SMD:C_0603_1608Metric | 15
C104 | 1nF |  | Capacitor_SMD:C_0603_1608Metric | 1
C201,C204 | 2.2uF | 25V | Capacitor_SMD:C_0805_2012Metric | 2
C203,C206 | 220nF | 50V | Capacitor_SMD:C_0805_2012Metric | 2
C301,C302 | 100nF | 250V C0G | Capacitor_SMD:C_1812_4532Metric | 2
C303 | 3.3nF | 250V C0G | Capacitor_SMD:C_1812_4532Metric | 1
C304 | 82nF | 250V C0G | Capacitor_SMD:C_1812_4532Metric | 1
C305 | 5.6nF | 250V C0G | Capacitor_SMD:C_1812_4532Metric | 1
C404 | 22uF | 25V | Capacitor_SMD:C_1210_3225Metric | 1
C409 | 22uF | 16V | Capacitor_SMD:C_1210_3225Metric | 1
C411,C413,C506,C508 | 1uF |  | Capacitor_SMD:C_0603_1608Metric | 4
C412,C507,C509 | 10nF |  | Capacitor_SMD:C_0603_1608Metric | 3
C505 | 4.7uF |  | Capacitor_SMD:C_0805_2012Metric | 1
C510,C511 | 15pF |  | Capacitor_SMD:C_0603_1608Metric | 2
D101 | SMAJ28A |  | Diode_SMD:D_SMA | 1
D401,D402 | SS110 |  | Diode_SMD:D_SMA | 2
D501 | LED_G |  | LED_SMD:LED_0603_1608Metric | 1
F101 | 10A |  | Fuse:Fuse_Littelfuse-NANO2-451_453 | 1
FB501 | 600R@100MHz |  | Inductor_SMD:L_0603_1608Metric | 1
J101 | XT30_24V_IN |  | Connector_AMASS:AMASS_XT30PW-M_1x02_P2.50mm_Horizontal | 1
J301 | TX_COIL |  | TerminalBlock_Phoenix:TerminalBlock_Phoenix_MKDS-1,5-2-5.08_1x02_P5.08mm_Horizontal | 1
J501 | SWD |  | Connector_PinHeader_2.54mm:PinHeader_1x05_P2.54mm_Vertical | 1
J502 | UART |  | Connector_PinHeader_2.54mm:PinHeader_1x04_P2.54mm_Vertical | 1
L301 | 6uH |  | Inductor_SMD:L_12x12mm_H8mm | 1
L302 | 20uH |  |  | 1
L401 | 47uH |  | Inductor_SMD:L_Taiyo-Yuden_NR-50xx | 1
L402 | 33uH |  | Inductor_SMD:L_Taiyo-Yuden_NR-50xx | 1
Q1,Q2,Q3,Q4 | BSC070N10NS3G |  | Package_SON:Infineon_PG-TDSON-8_6.15x5.15mm | 4
R1,R2,R3,R4 | 10R |  | Resistor_SMD:R_0603_1608Metric | 4
R6,R7,R8,R9,R104,R403,R406,R501 | 10k |  | Resistor_SMD:R_0603_1608Metric | 8
R101 | 2m |  | Resistor_SMD:R_Shunt_Vishay_WSK2512_6332Metric_T1.19mm | 1
R102 | 100 |  | Resistor_SMD:R_0603_1608Metric | 1
R103 | 150k |  | Resistor_SMD:R_0603_1608Metric | 1
R401,R404 | 100k |  | Resistor_SMD:R_0603_1608Metric | 2
R402 | 147k |  | Resistor_SMD:R_0603_1608Metric | 1
R405 | 54.9k |  | Resistor_SMD:R_0603_1608Metric | 1
R502 | 1k |  | Resistor_SMD:R_0603_1608Metric | 1
U101 | INA240A2D |  | Package_SO:SOIC-8_3.9x4.9mm_P1.27mm | 1
U201,U202 | UCC27211 |  | Package_SON:HVSON-8-1EP_4x4mm_P0.8mm_EP2.2x3.1mm | 2
U401,U402 | LMR16006X |  | Package_TO_SOT_SMD:SOT-23-6 | 2
U403 | TC2185-3.3 |  | Package_TO_SOT_SMD:SOT-23-5 | 1
U501 | STM32G474CETx |  | Package_QFP:LQFP-48_7x7mm_P0.5mm | 1
Y501 | 8MHz |  | Crystal:Crystal_SMD_3225-4Pin_3.2x2.5mm | 1

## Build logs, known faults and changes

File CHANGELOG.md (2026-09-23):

# 更新日志

## v0.1.0（2026-09-23）

首次发布。

- 发射板（82 × 60 mm）与接收板（75 × 60 mm）的原理图和 4 层 PCB，KiCad 10。
- 原理图 ERC 0；PCB DRC 0 错误、0 未连接。
- 两块板的生产文件：Gerber、钻孔、BOM、贴片坐标、装配图、DRC 报告。
- 原理图 PDF 与 3D 渲染图。

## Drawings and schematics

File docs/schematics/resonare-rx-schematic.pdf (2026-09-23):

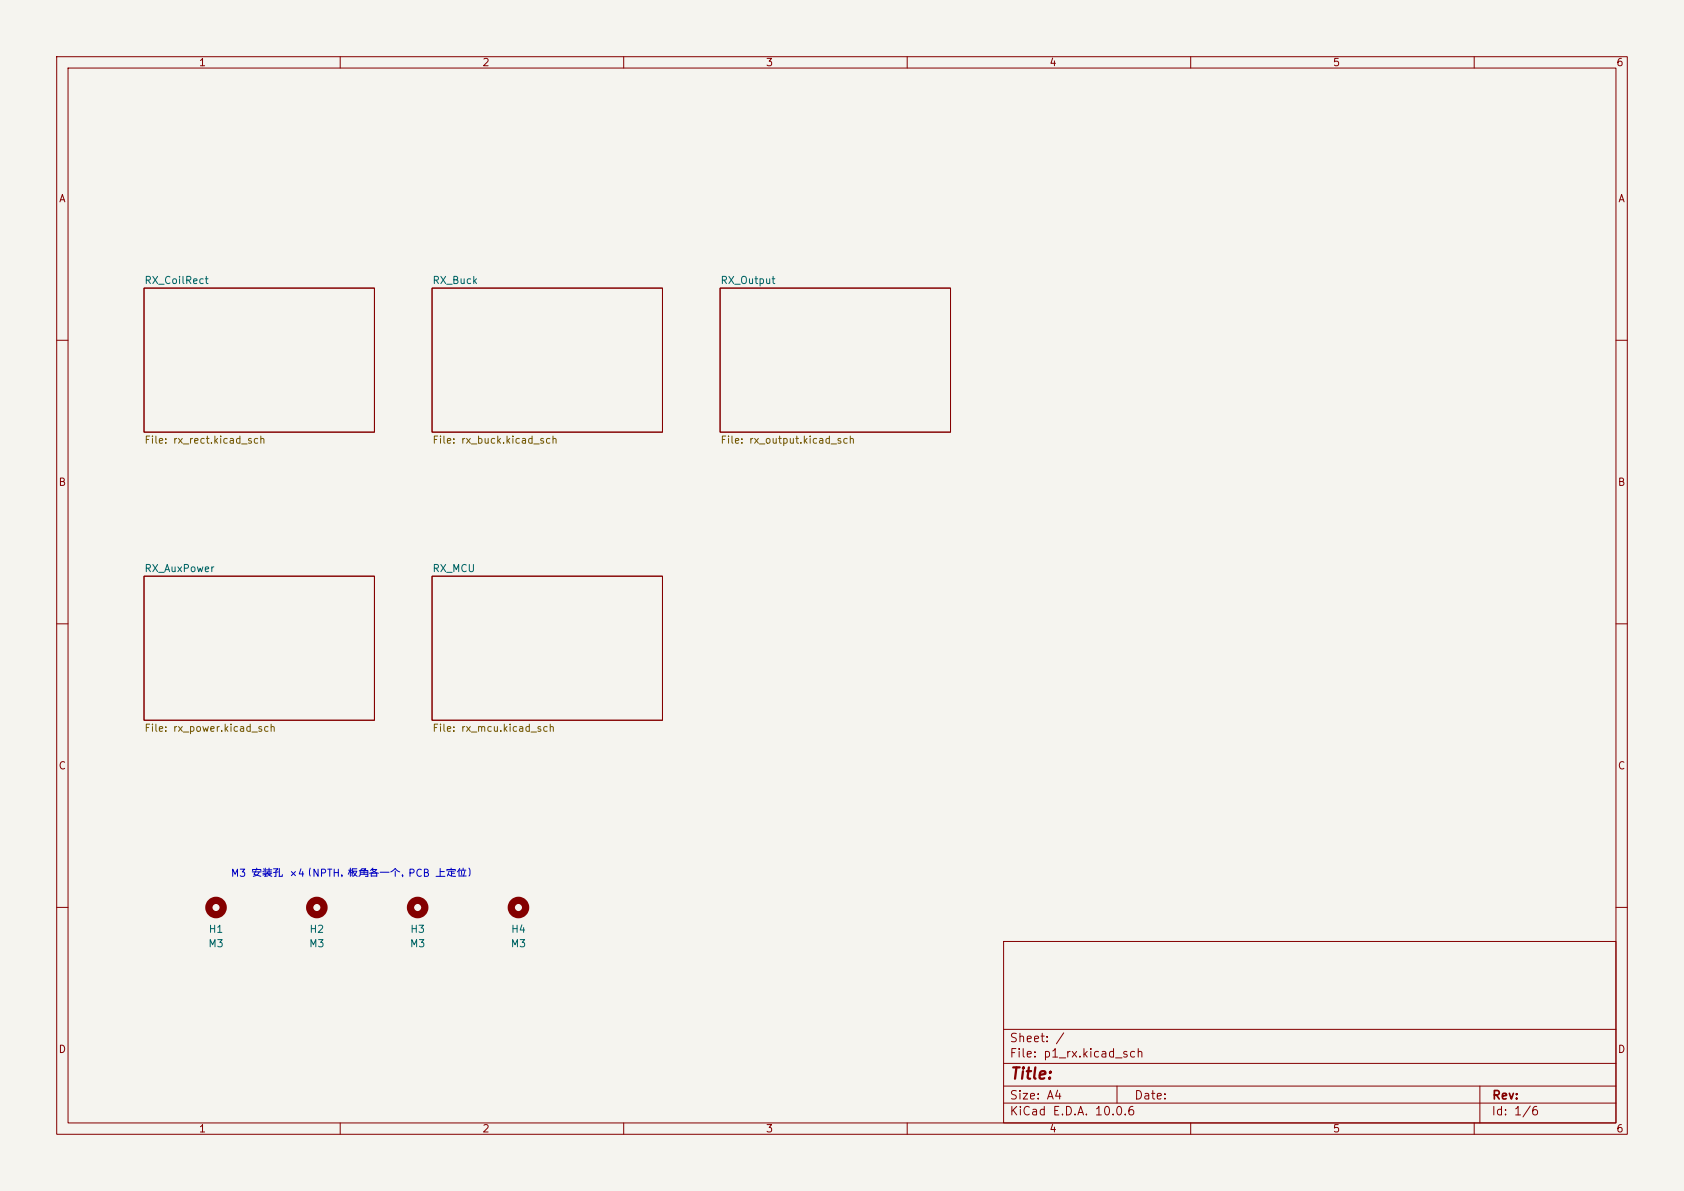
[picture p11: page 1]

Size: A4 | Rev:
KiCad E.D.A. 10.0.6 | Id: 1/6

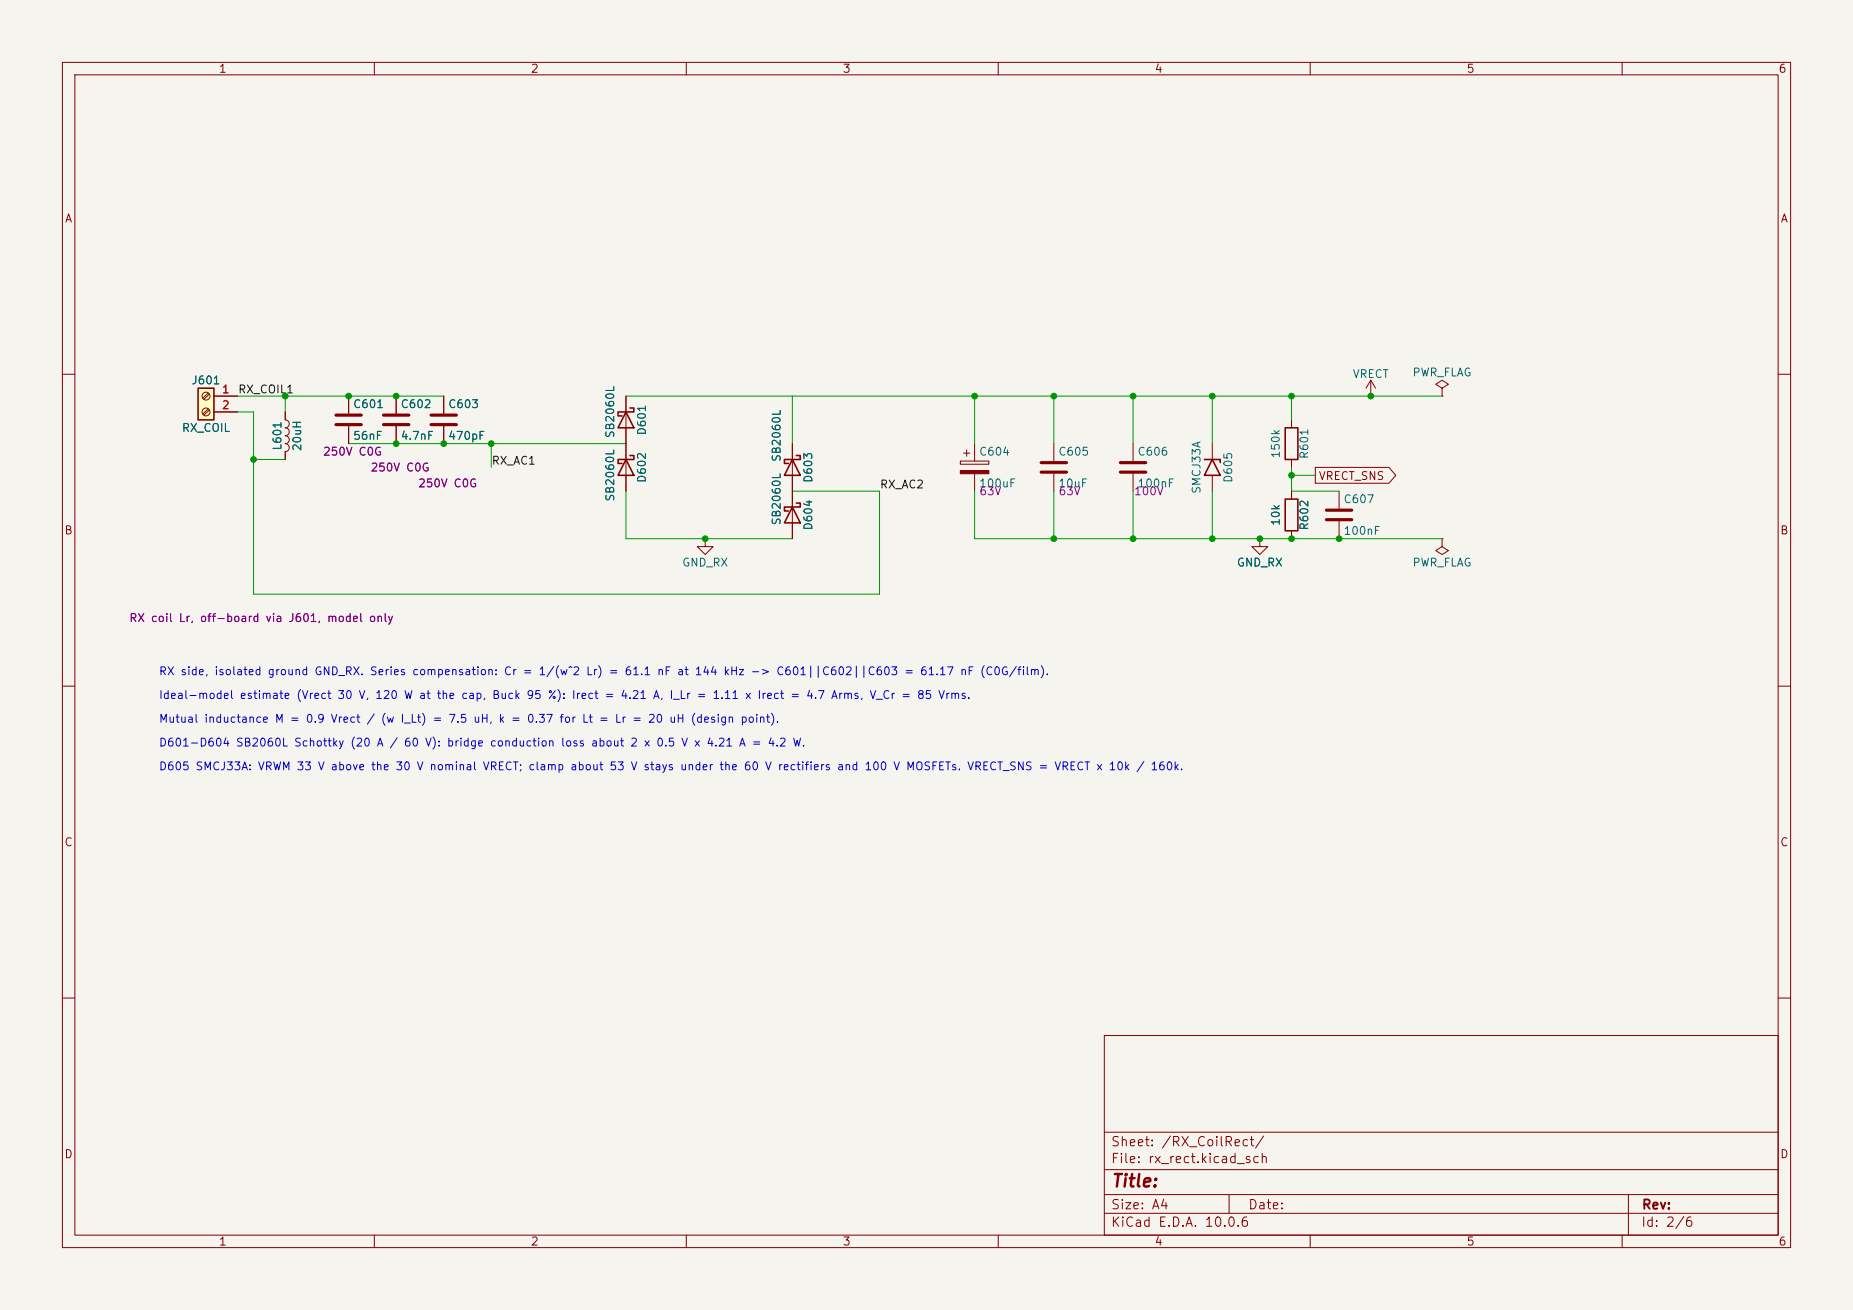
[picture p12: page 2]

RX coil Lr, off-board via J601, model only C601

Ideal-model estimate (Vrect 30 V, 120 W at the cap, Buck 95 %): Irect = 4.21 A, I_Lr = 1.11 x Irect = 4.7 Arms, V_Cr = 85 Vrms. RX side, isolated ground GND_RX. Series compensation: Cr = 1/(w^2 Lr) = 61.1 nF at 144 kHz -> C601||C602||C603 = 61.17 nF (C0G/film). C602

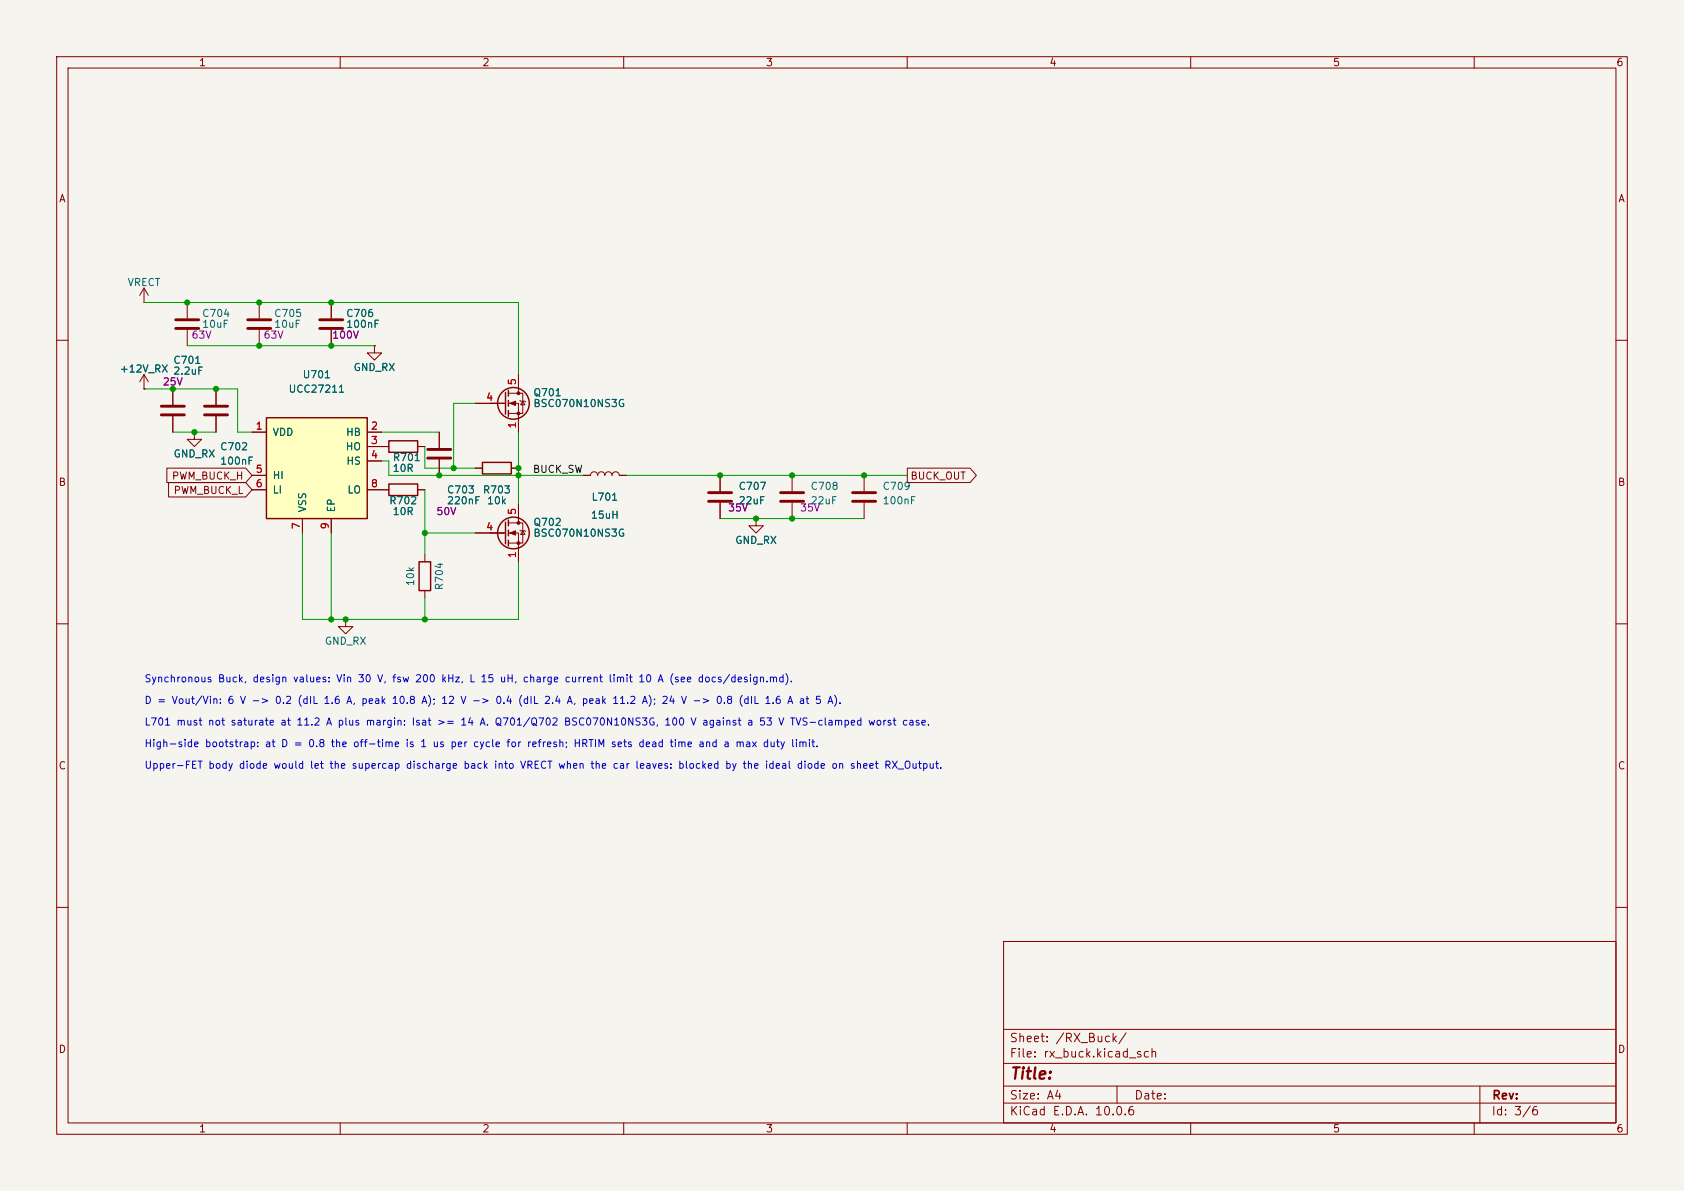
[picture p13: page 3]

High-side bootstrap: at D = 0.8 the off-time is 1 us per cycle for refresh; HRTIM sets dead time and a max duty limit. Q701 BSC070N10NS3G

Synchronous Buck, design values: Vin 30 V, fsw 200 kHz, L 15 uH, charge current limit 10 A (see docs/design.md).

L701 must not saturate at 11.2 A plus margin: Isat >= 14 A. Q701/Q702 BSC070N10NS3G, 100 V against a 53 V TVS-clamped worst case. D = Vout/Vin: 6 V -> 0.2 (dIL 1.6 A, peak 10.8 A); 12 V -> 0.4 (dIL 2.4 A, peak 11.2 A); 24 V -> 0.8 (dIL 1.6 A at 5 A).

Upper-FET body diode would let the supercap discharge back into VRECT when the car leaves: blocked by the ideal diode on sheet RX_Output.

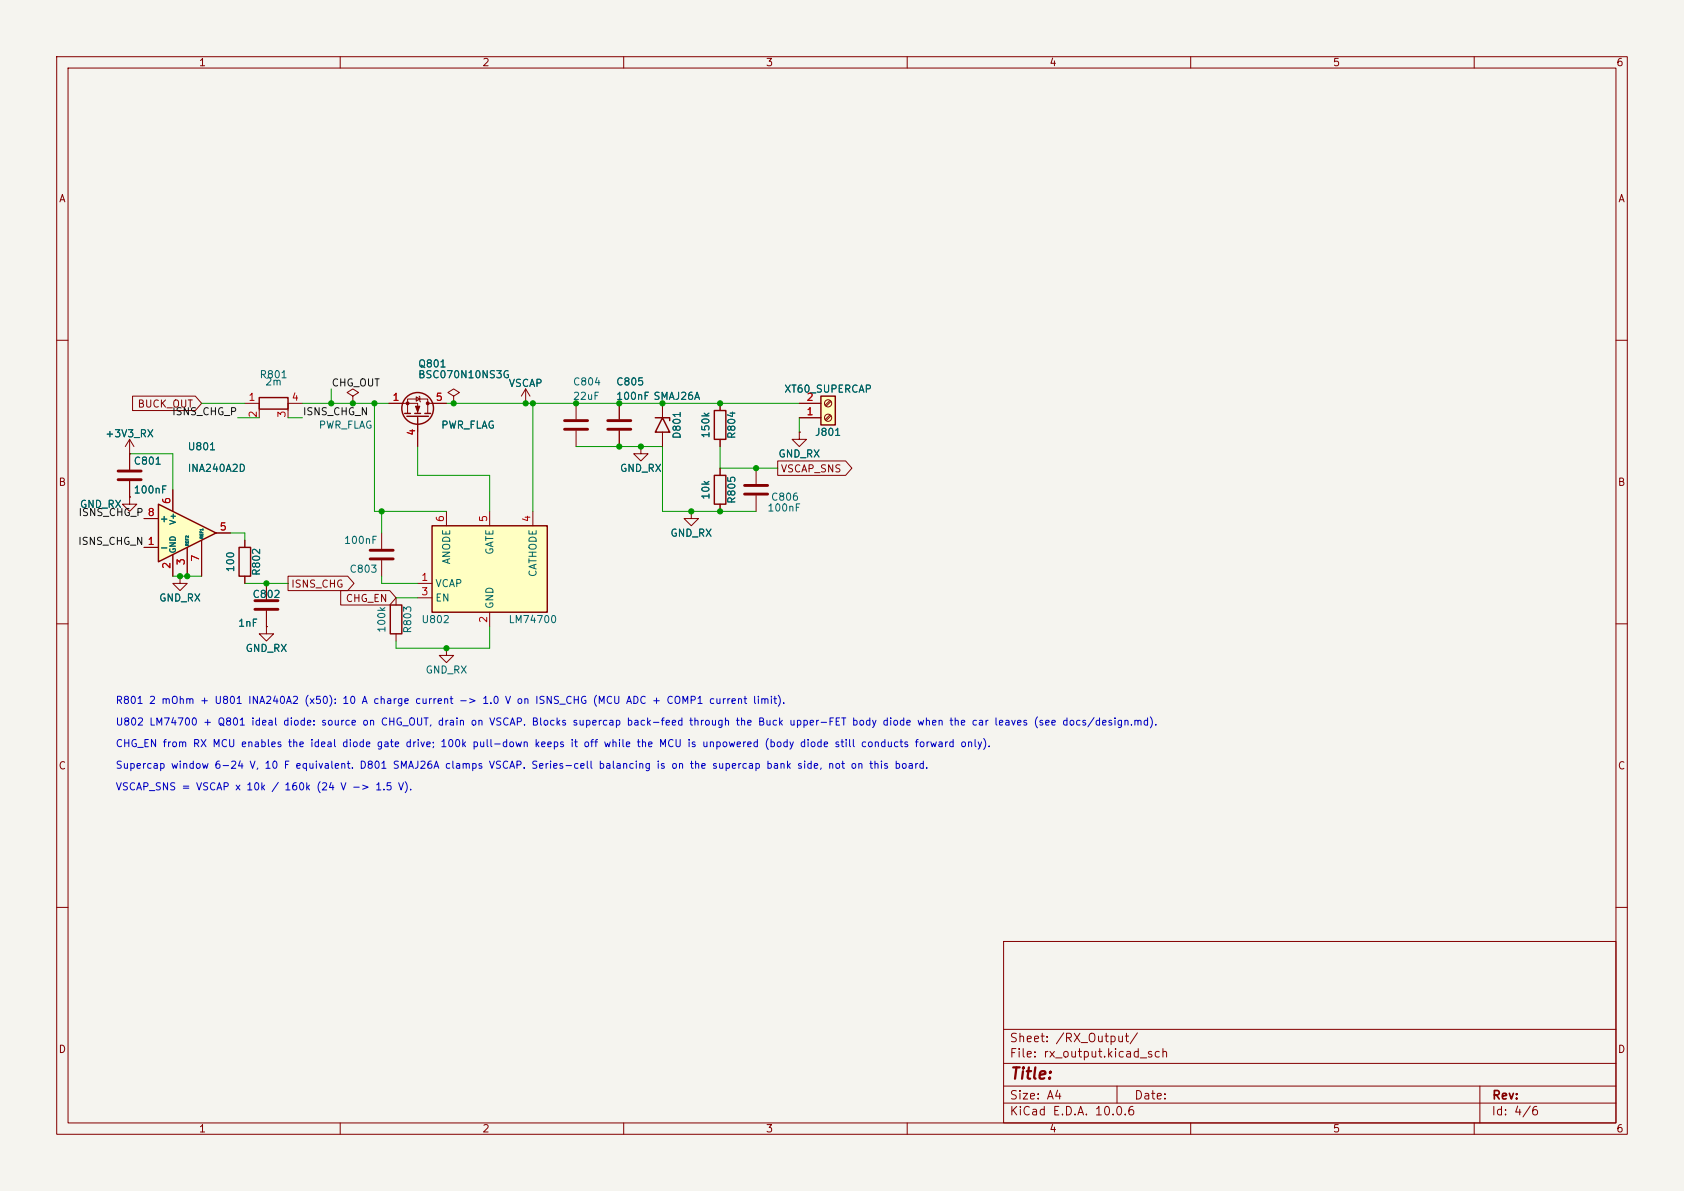
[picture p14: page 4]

R801 2 mOhm + U801 INA240A2 (x50): 10 A charge current -> 1.0 V on ISNS_CHG (MCU ADC + COMP1 current limit). CHG_EN from RX MCU enables the ideal diode gate drive; 100k pull-down keeps it off while the MCU is unpowered (body diode still conducts forward only).

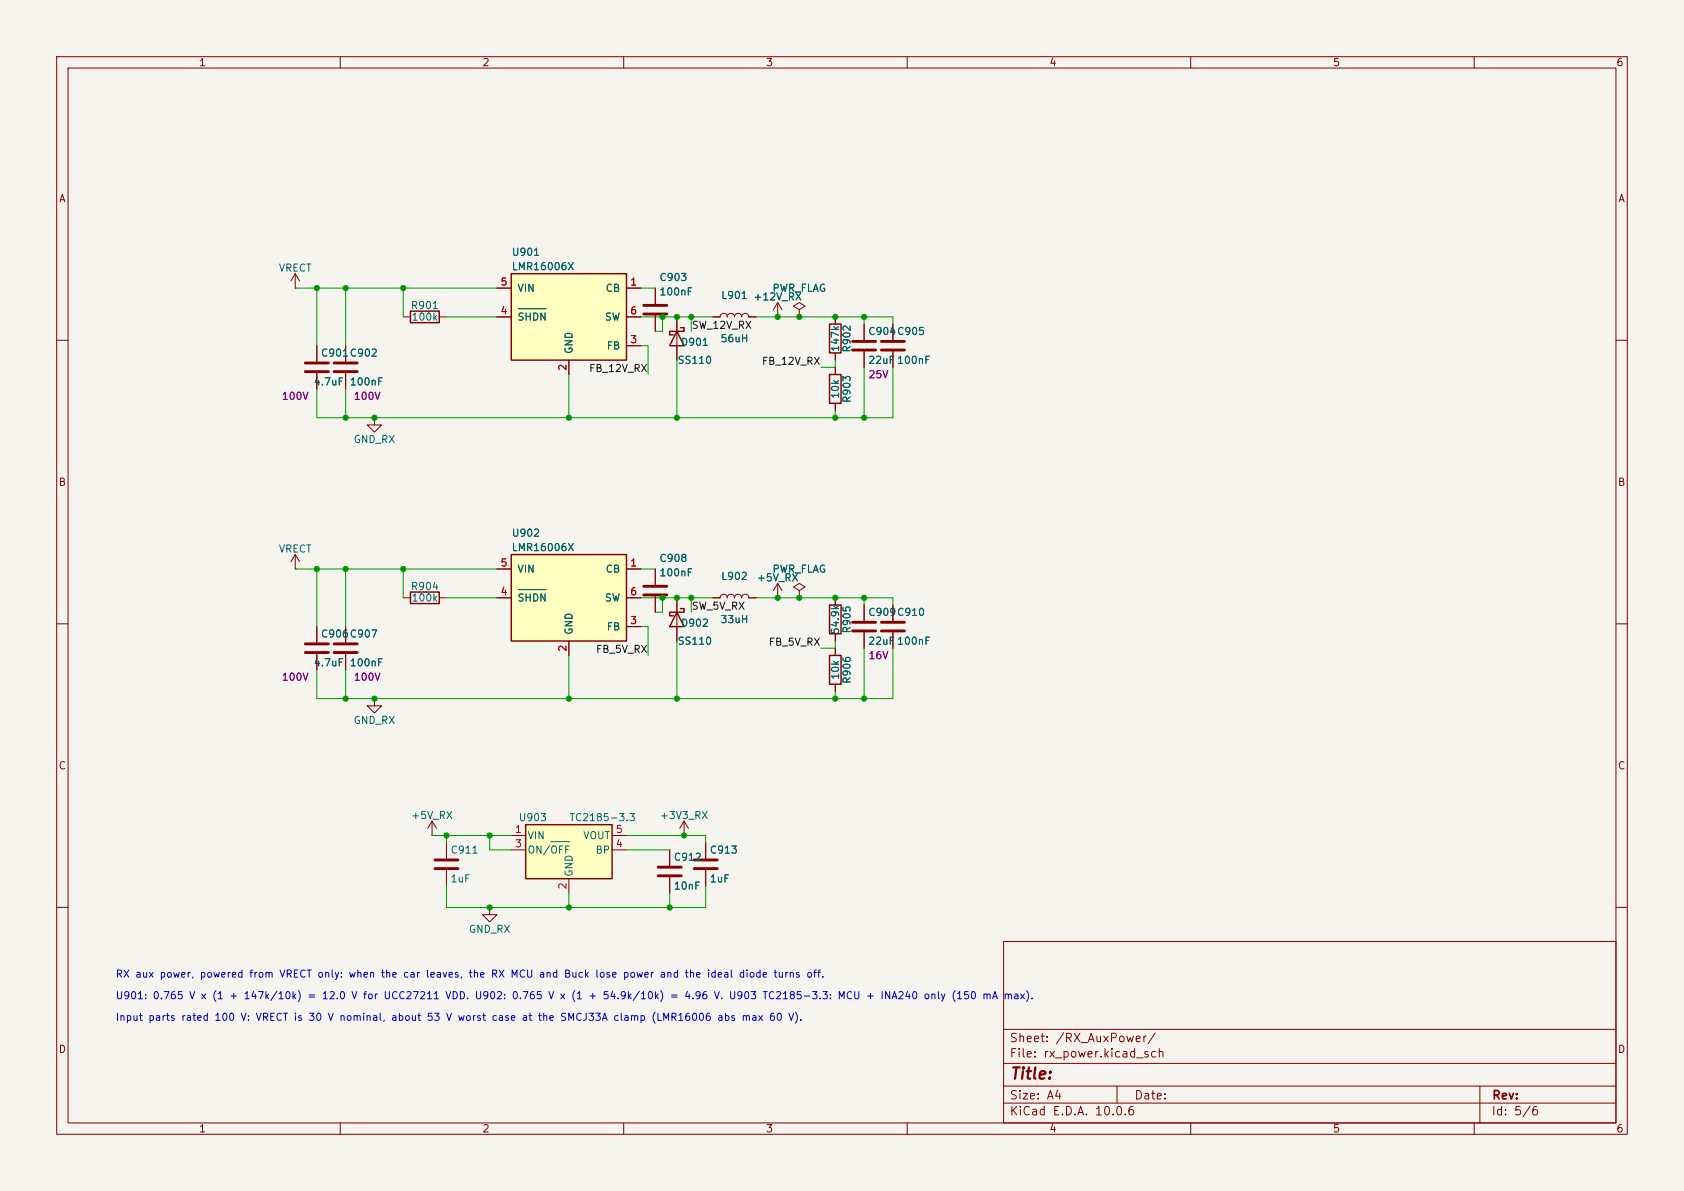
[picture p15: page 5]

FB_12V_RX RX aux power, powered from VRECT only: when the car leaves, the RX MCU and Buck lose power and the ideal diode turns off.

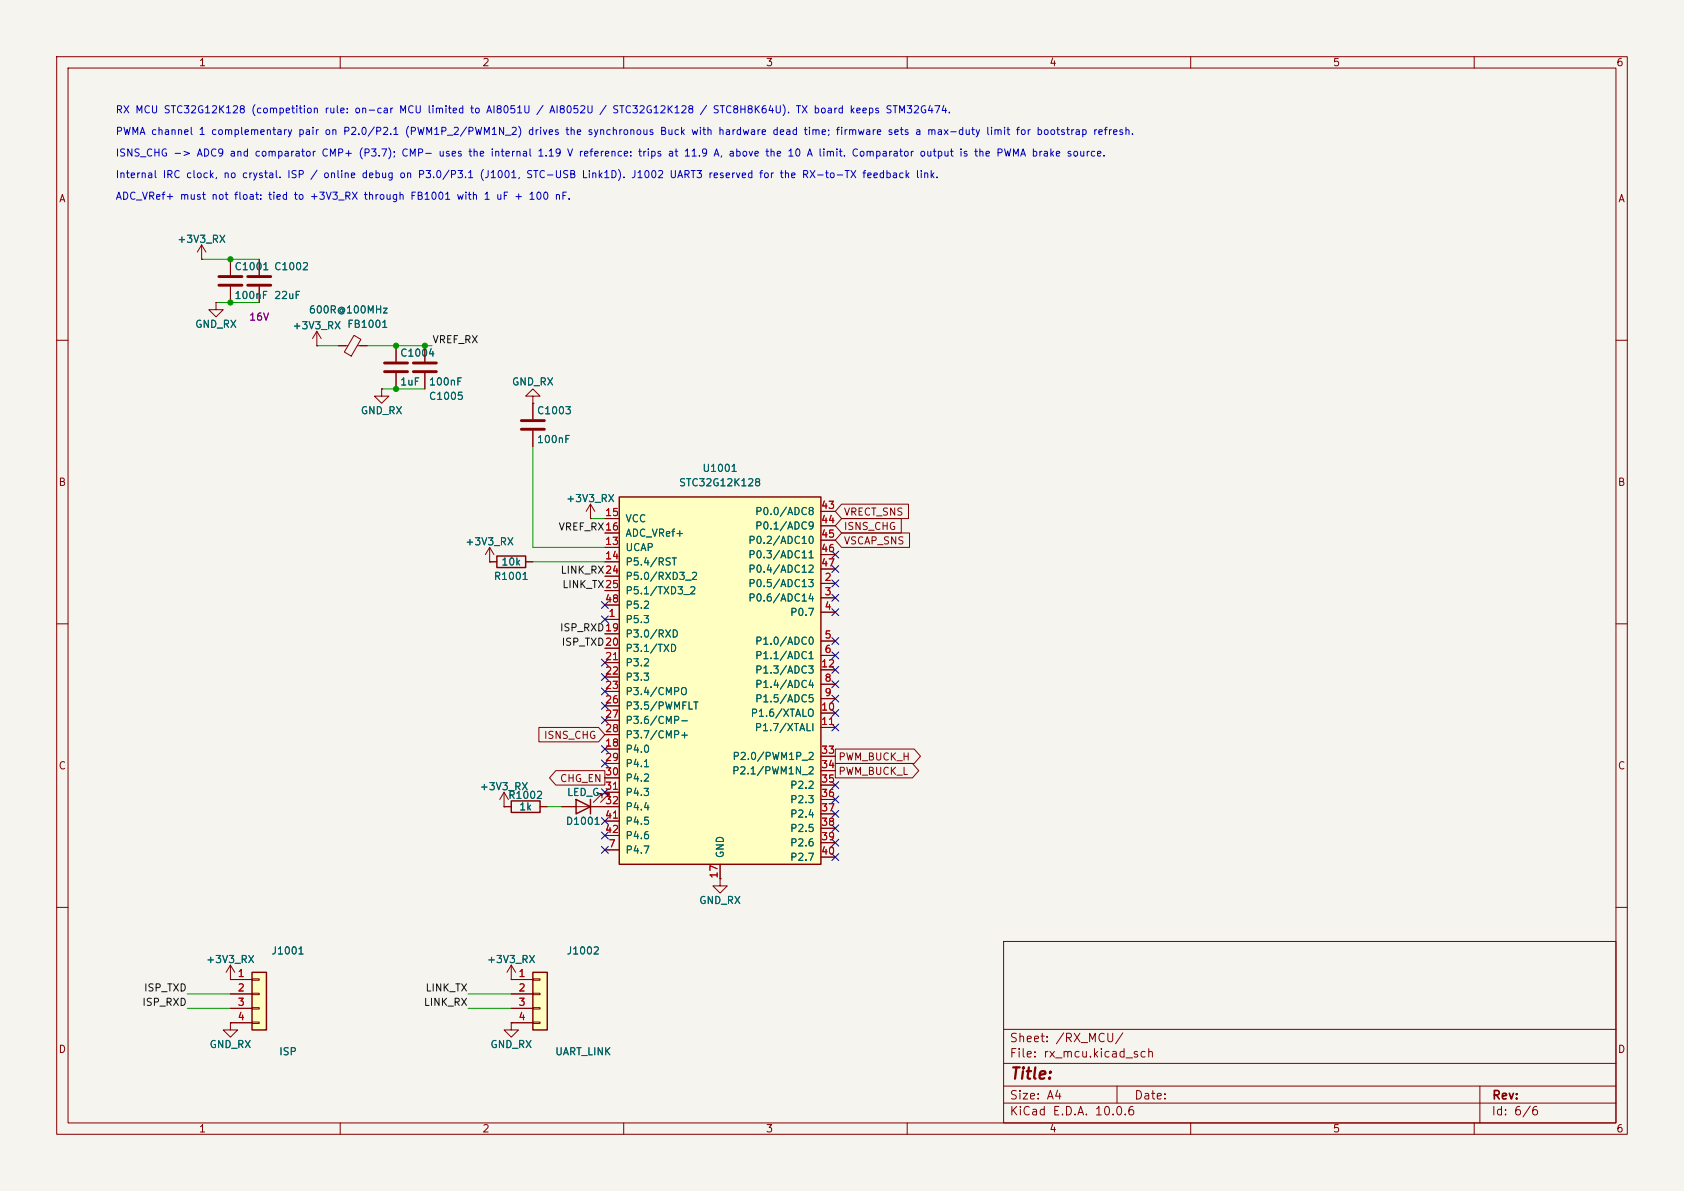
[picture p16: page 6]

RX MCU STC32G12K128 (competition rule: on-car MCU limited to AI8051U / AI8052U / STC32G12K128 / STC8H8K64U). TX board keeps STM32G474. ADC_VRef+ must not float: tied to +3V3_RX through FB1001 with 1 uF + 100 nF.
600R@100MHz +3V3_RX +3V3_RX

ISNS_CHG -> ADC9 and comparator CMP+ (P3.7); CMP- uses the internal 1.19 V reference: trips at 11.9 A, above the 10 A limit. Comparator output is the PWMA brake source. PWMA channel 1 complementary pair on P2.0/P2.1 (PWM1P_2/PWM1N_2) drives the synchronous Buck with hardware dead time; firmware sets a max-duty limit for bootstrap refresh. FB1001

Internal IRC clock, no crystal. ISP / online debug on P3.0/P3.1 (J1001, STC-USB Link1D). J1002 UART3 reserved for the RX-to-TX feedback link.

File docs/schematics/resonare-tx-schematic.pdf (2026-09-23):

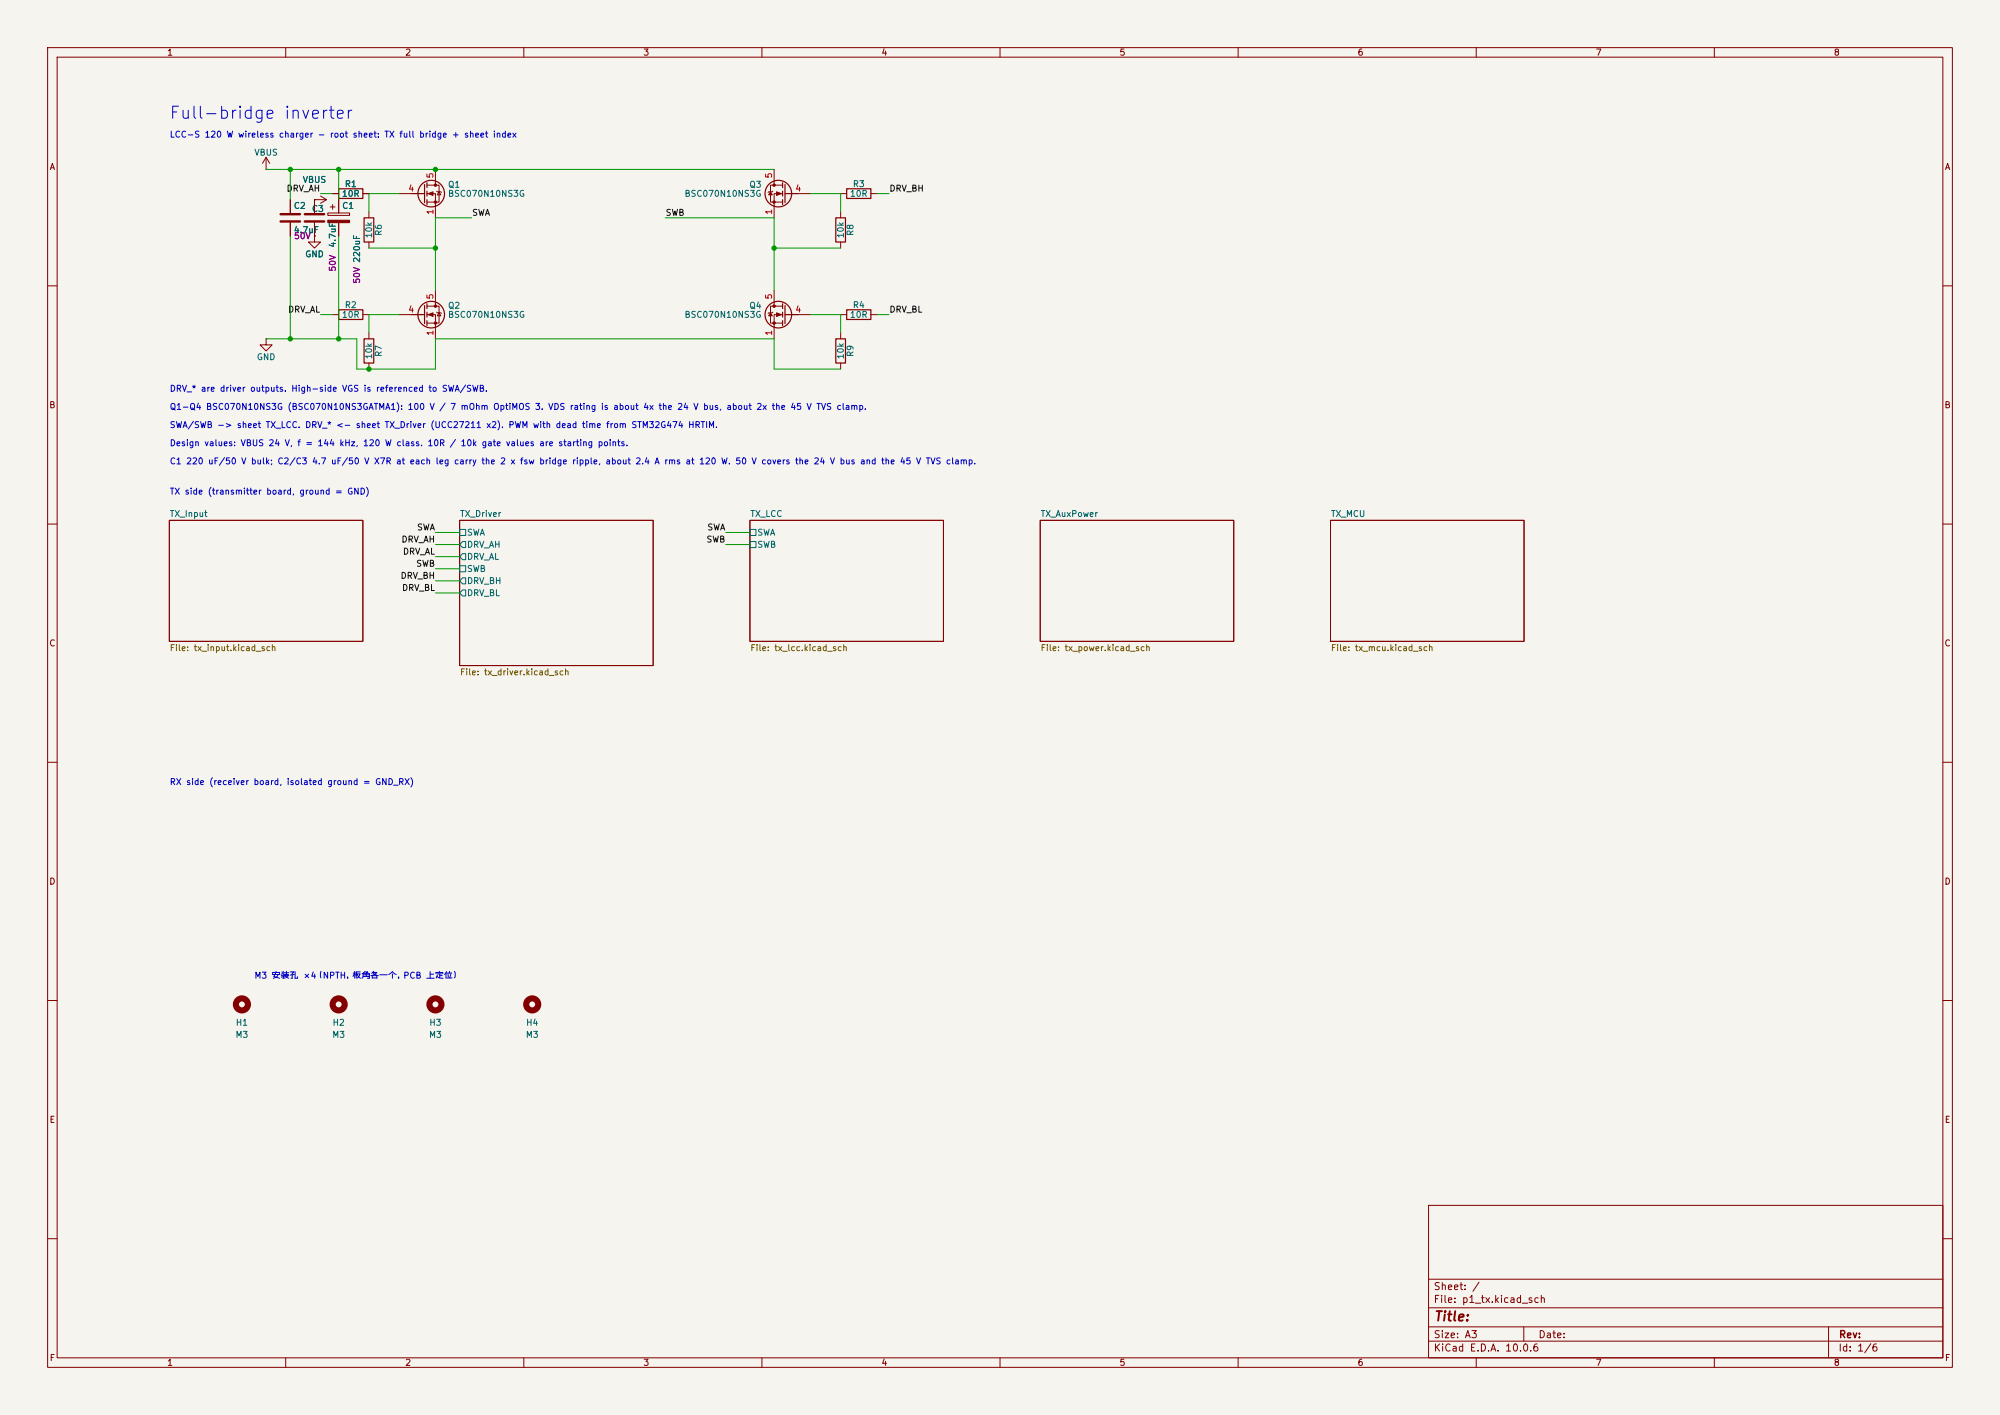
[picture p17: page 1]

RX side (receiver board, isolated ground = GND_RX) TX side (transmitter board, ground = GND) C2
SWA DRV_BH

LCC-S 120 W wireless charger - root sheet: TX full bridge + sheet index SWA/SWB -> sheet TX_LCC. DRV_* <- sheet TX_Driver (UCC27211 x2). PWM with dead time from STM32G474 HRTIM. DRV_* are driver outputs. High-side VGS is referenced to SWA/SWB.

Q1-Q4 BSC070N10NS3G (BSC070N10NS3GATMA1): 100 V / 7 mOhm OptiMOS 3. VDS rating is about 4x the 24 V bus, about 2x the 45 V TVS clamp. C1 220 uF/50 V bulk; C2/C3 4.7 uF/50 V X7R at each leg carry the 2 x fsw bridge ripple, about 2.4 A rms at 120 W. 50 V covers the 24 V bus and the 45 V TVS clamp.

Design values: VBUS 24 V, f = 144 kHz, 120 W class. 10R / 10k gate values are starting points.

Size: A3 | Rev: | F Date:
KiCad E.D.A. 10.0.6 | Id: 1/6

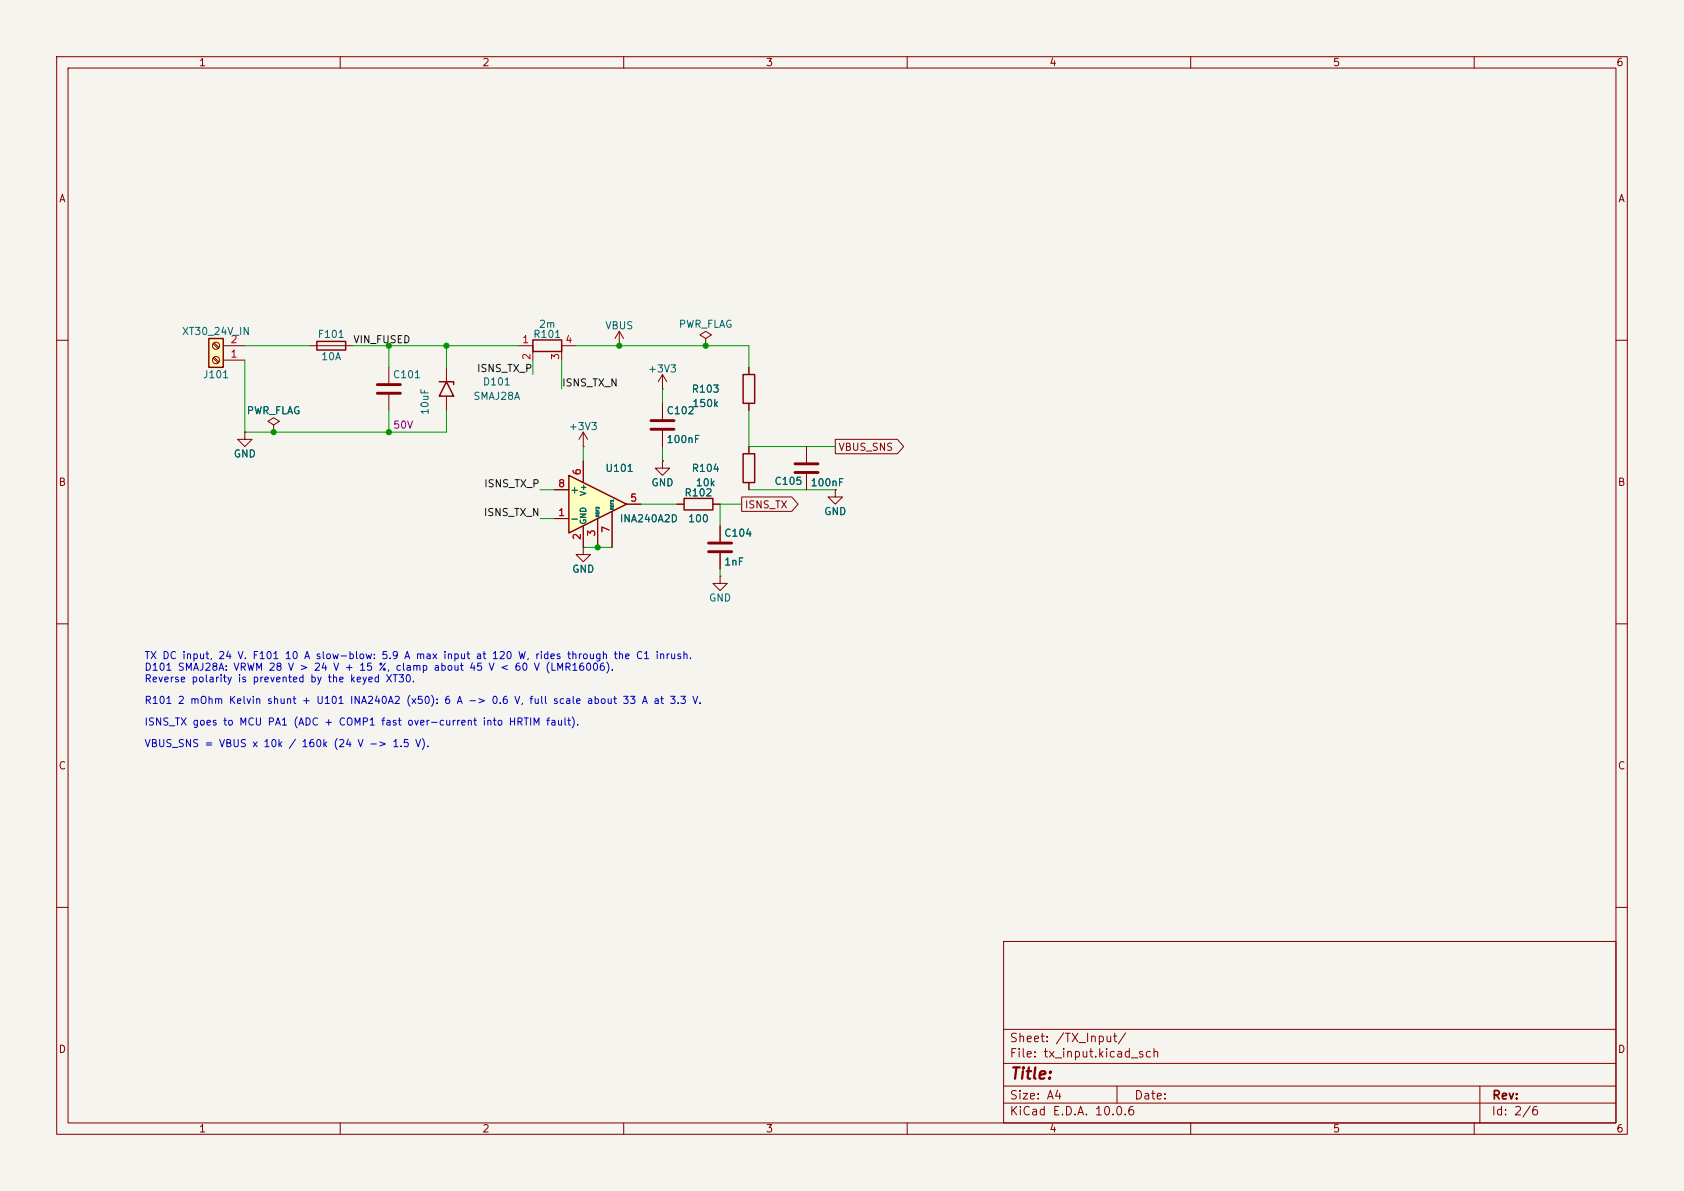
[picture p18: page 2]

ISNS_TX goes to MCU PA1 (ADC + COMP1 fast over-current into HRTIM fault). R101 2 mOhm Kelvin shunt + U101 INA240A2 (x50): 6 A -> 0.6 V, full scale about 33 A at 3.3 V. VBUS_SNS = VBUS x 10k / 160k (24 V -> 1.5 V). PWR_FLAG

TX DC input, 24 V. F101 10 A slow-blow: 5.9 A max input at 120 W, rides through the C1 inrush. D101 SMAJ28A: VRWM 28 V > 24 V + 15 %, clamp about 45 V < 60 V (LMR16006). Reverse polarity is prevented by the keyed XT30.

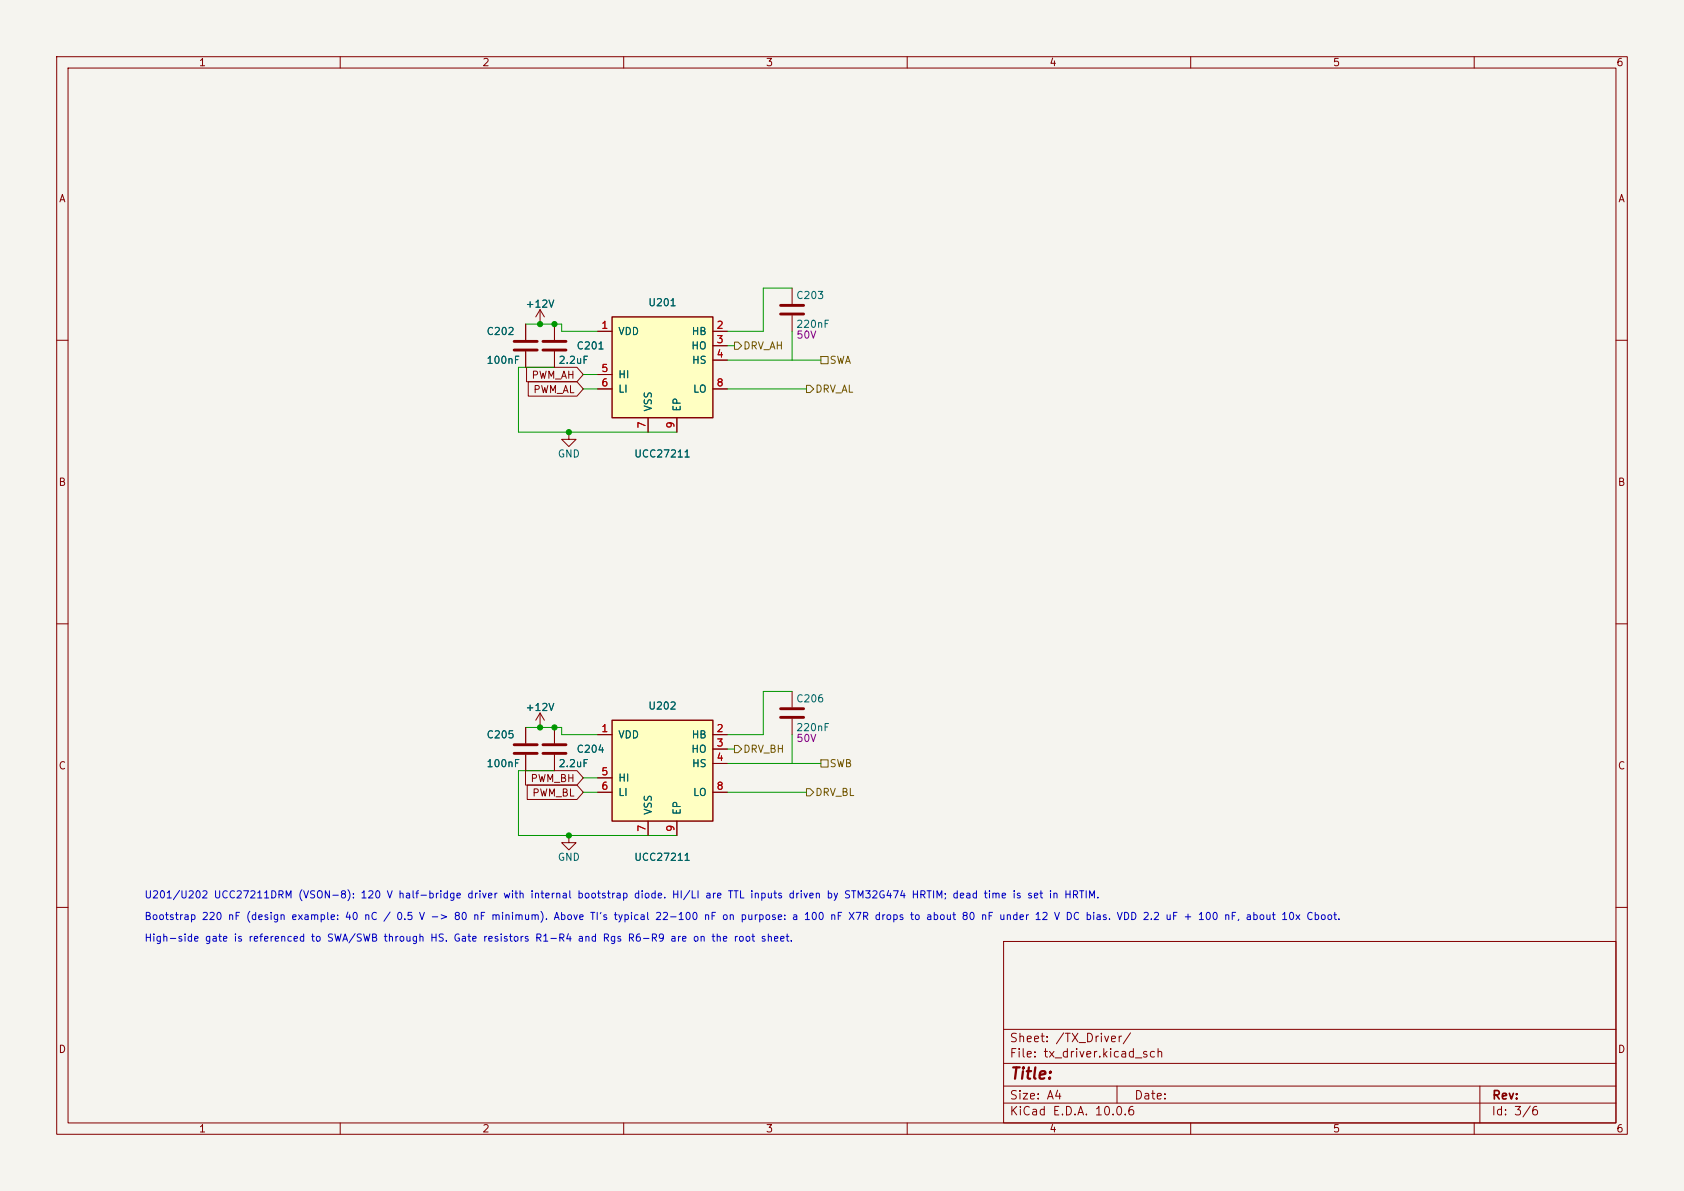
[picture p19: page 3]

High-side gate is referenced to SWA/SWB through HS. Gate resistors R1-R4 and Rgs R6-R9 are on the root sheet. Bootstrap 220 nF (design example: 40 nC / 0.5 V -> 80 nF minimum). Above TI's typical 22-100 nF on purpose: a 100 nF X7R drops to about 80 nF under 12 V DC bias. VDD 2.2 uF + 100 nF, about 10x Cboot. U201/U202 UCC27211DRM (VSON-8): 120 V half-bridge driver with internal bootstrap diode. HI/LI are TTL inputs driven by STM32G474 HRTIM; dead time is set in HRTIM. C204

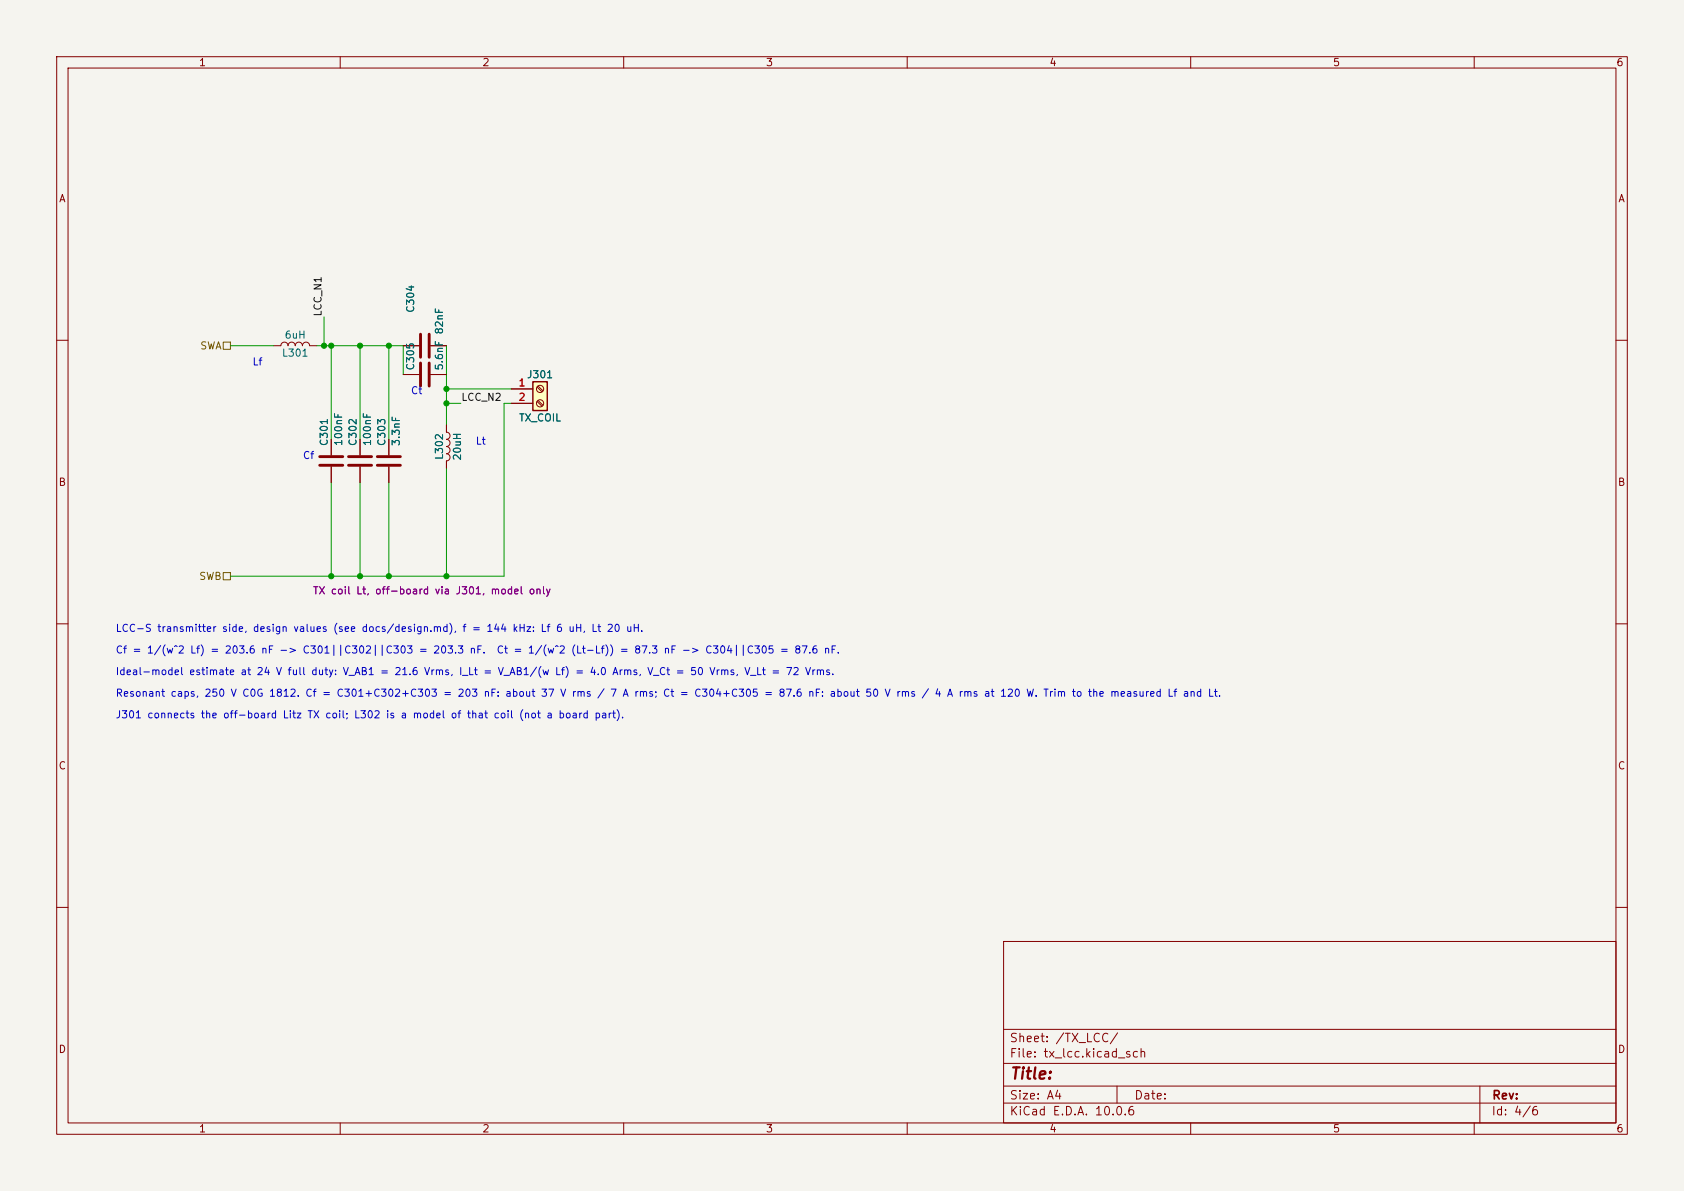
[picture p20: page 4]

TX coil Lt, off-board via J301, model only SWB

TX coil Lt, off-board via J301, model only

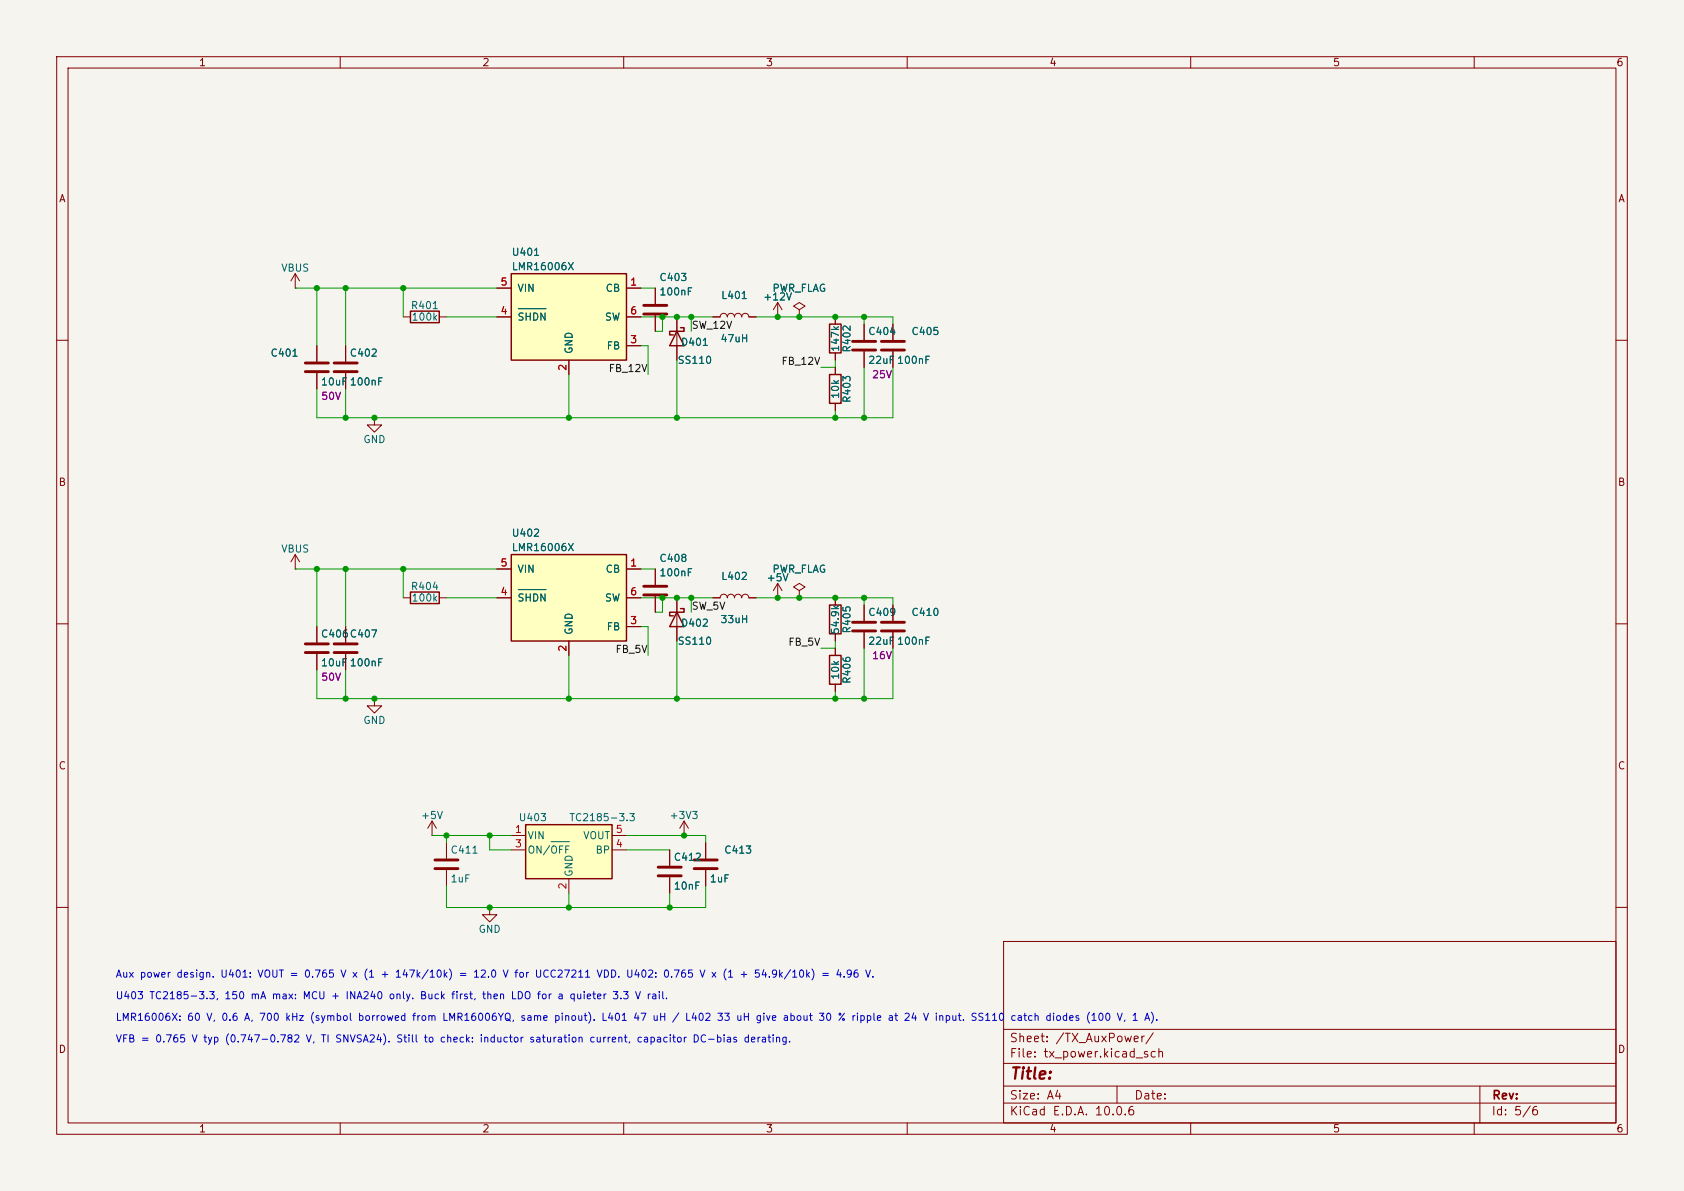
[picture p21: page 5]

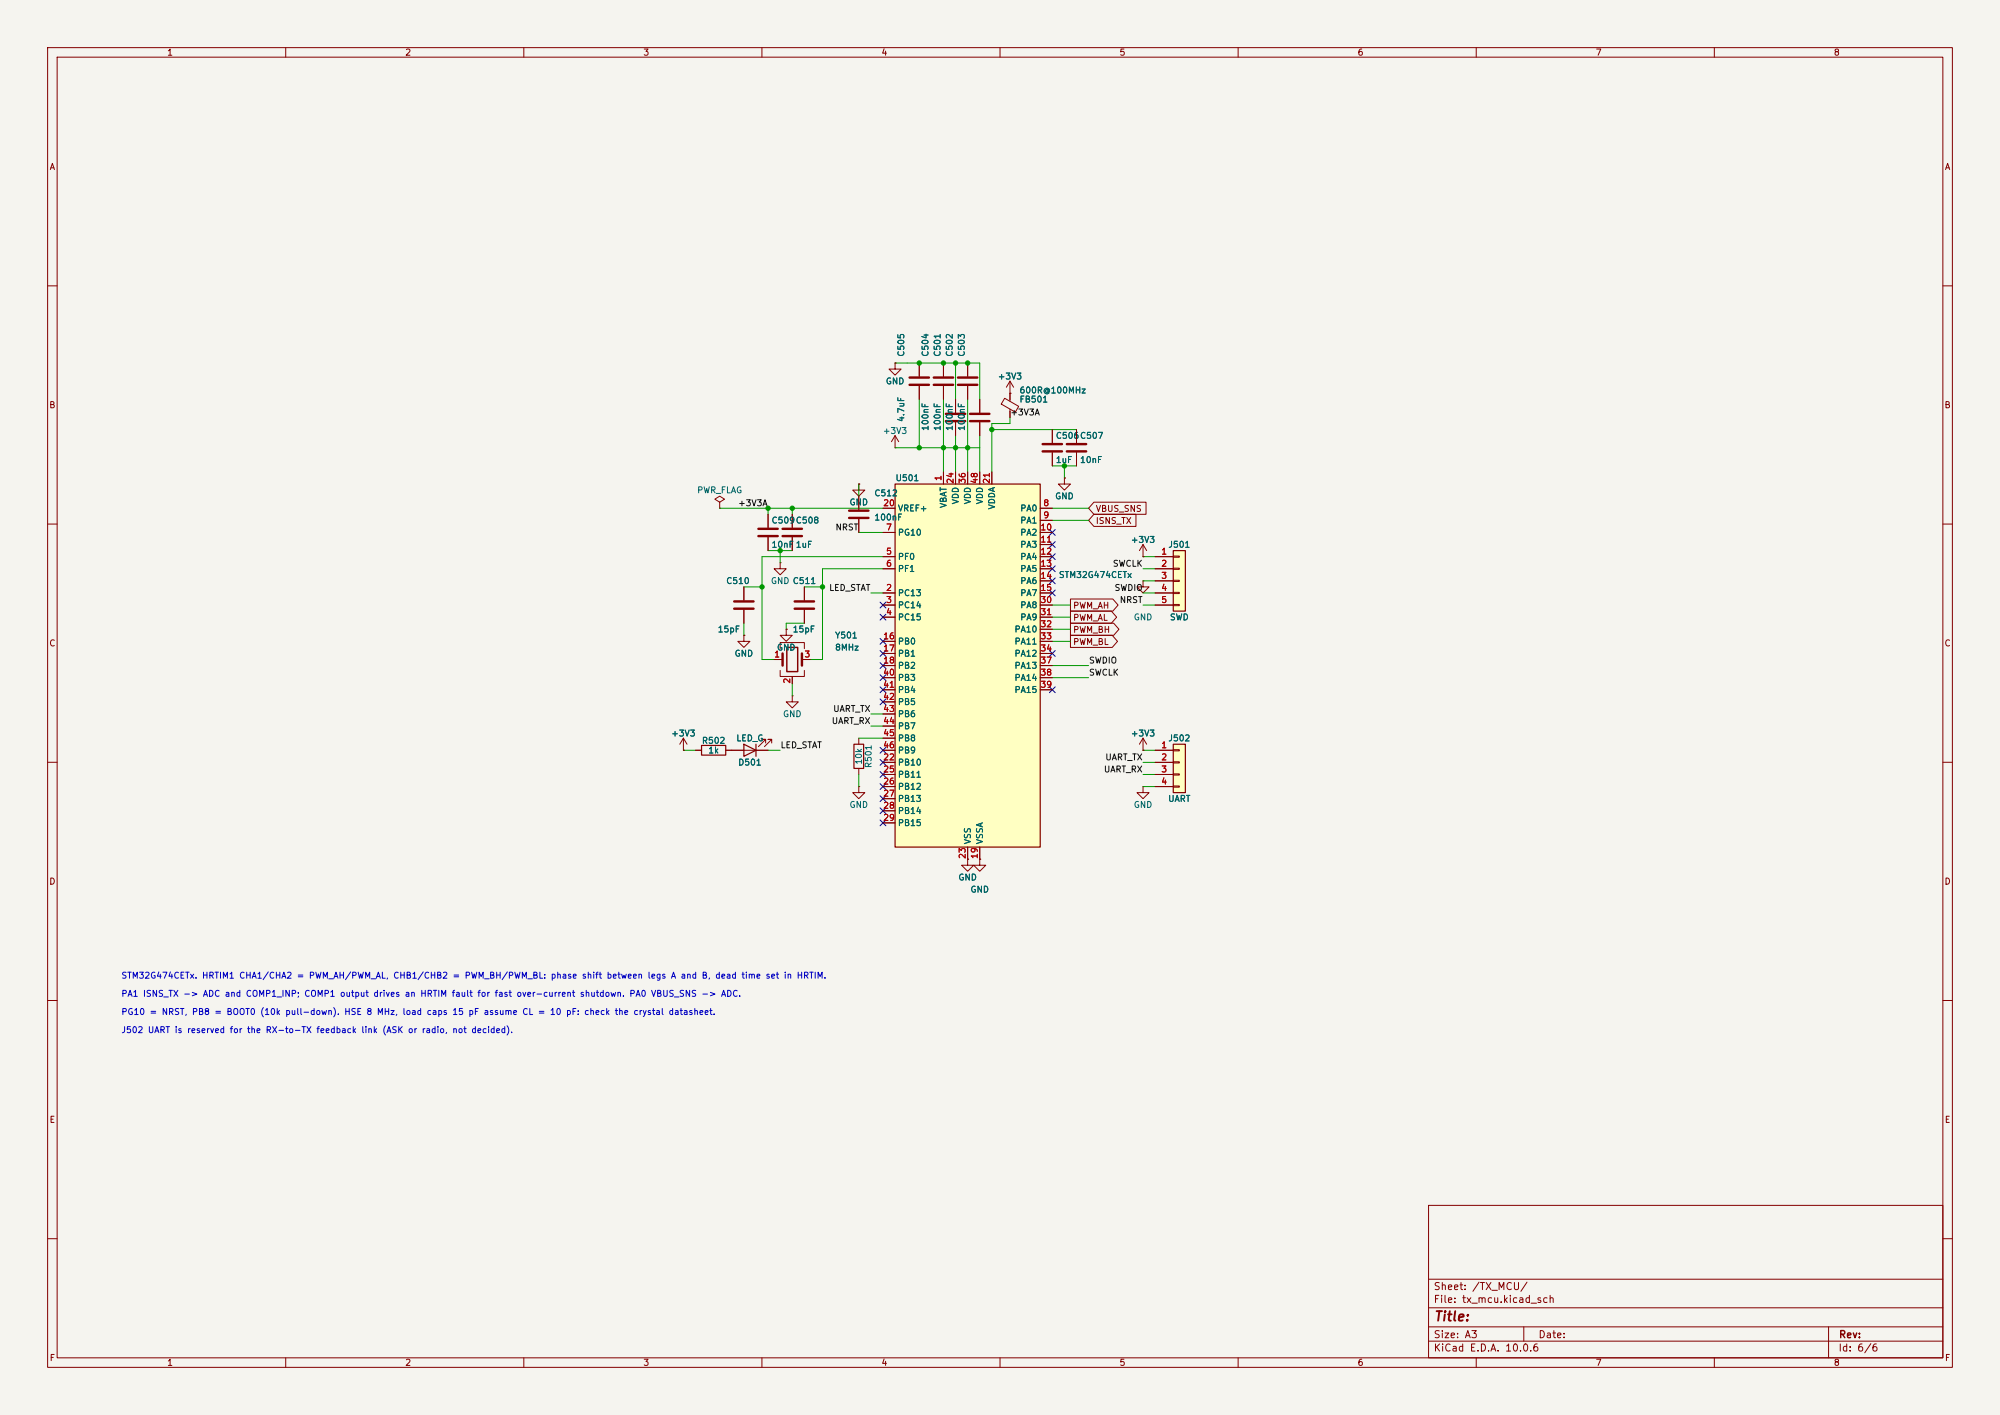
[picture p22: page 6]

PA1 ISNS_TX -> ADC and COMP1_INP; COMP1 output drives an HRTIM fault for fast over-current shutdown. PA0 VBUS_SNS -> ADC. PG10 = NRST, PB8 = BOOT0 (10k pull-down). HSE 8 MHz, load caps 15 pF assume CL = 10 pF: check the crystal datasheet. STM32G474CETx. HRTIM1 CHA1/CHA2 = PWM_AH/PWM_AL, CHB1/CHB2 = PWM_BH/PWM_BL: phase shift between legs A and B, dead time set in HRTIM. J502 UART is reserved for the RX-to-TX feedback link (ASK or radio, not decided).

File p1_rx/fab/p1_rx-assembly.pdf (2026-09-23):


Size: A4 | Rev:
KiCad E.D.A. 10.0.6 | Id: 1/1

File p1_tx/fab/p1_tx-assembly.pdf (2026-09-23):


Size: A4 | Rev:
KiCad E.D.A. 10.0.6 | Id: 1/1

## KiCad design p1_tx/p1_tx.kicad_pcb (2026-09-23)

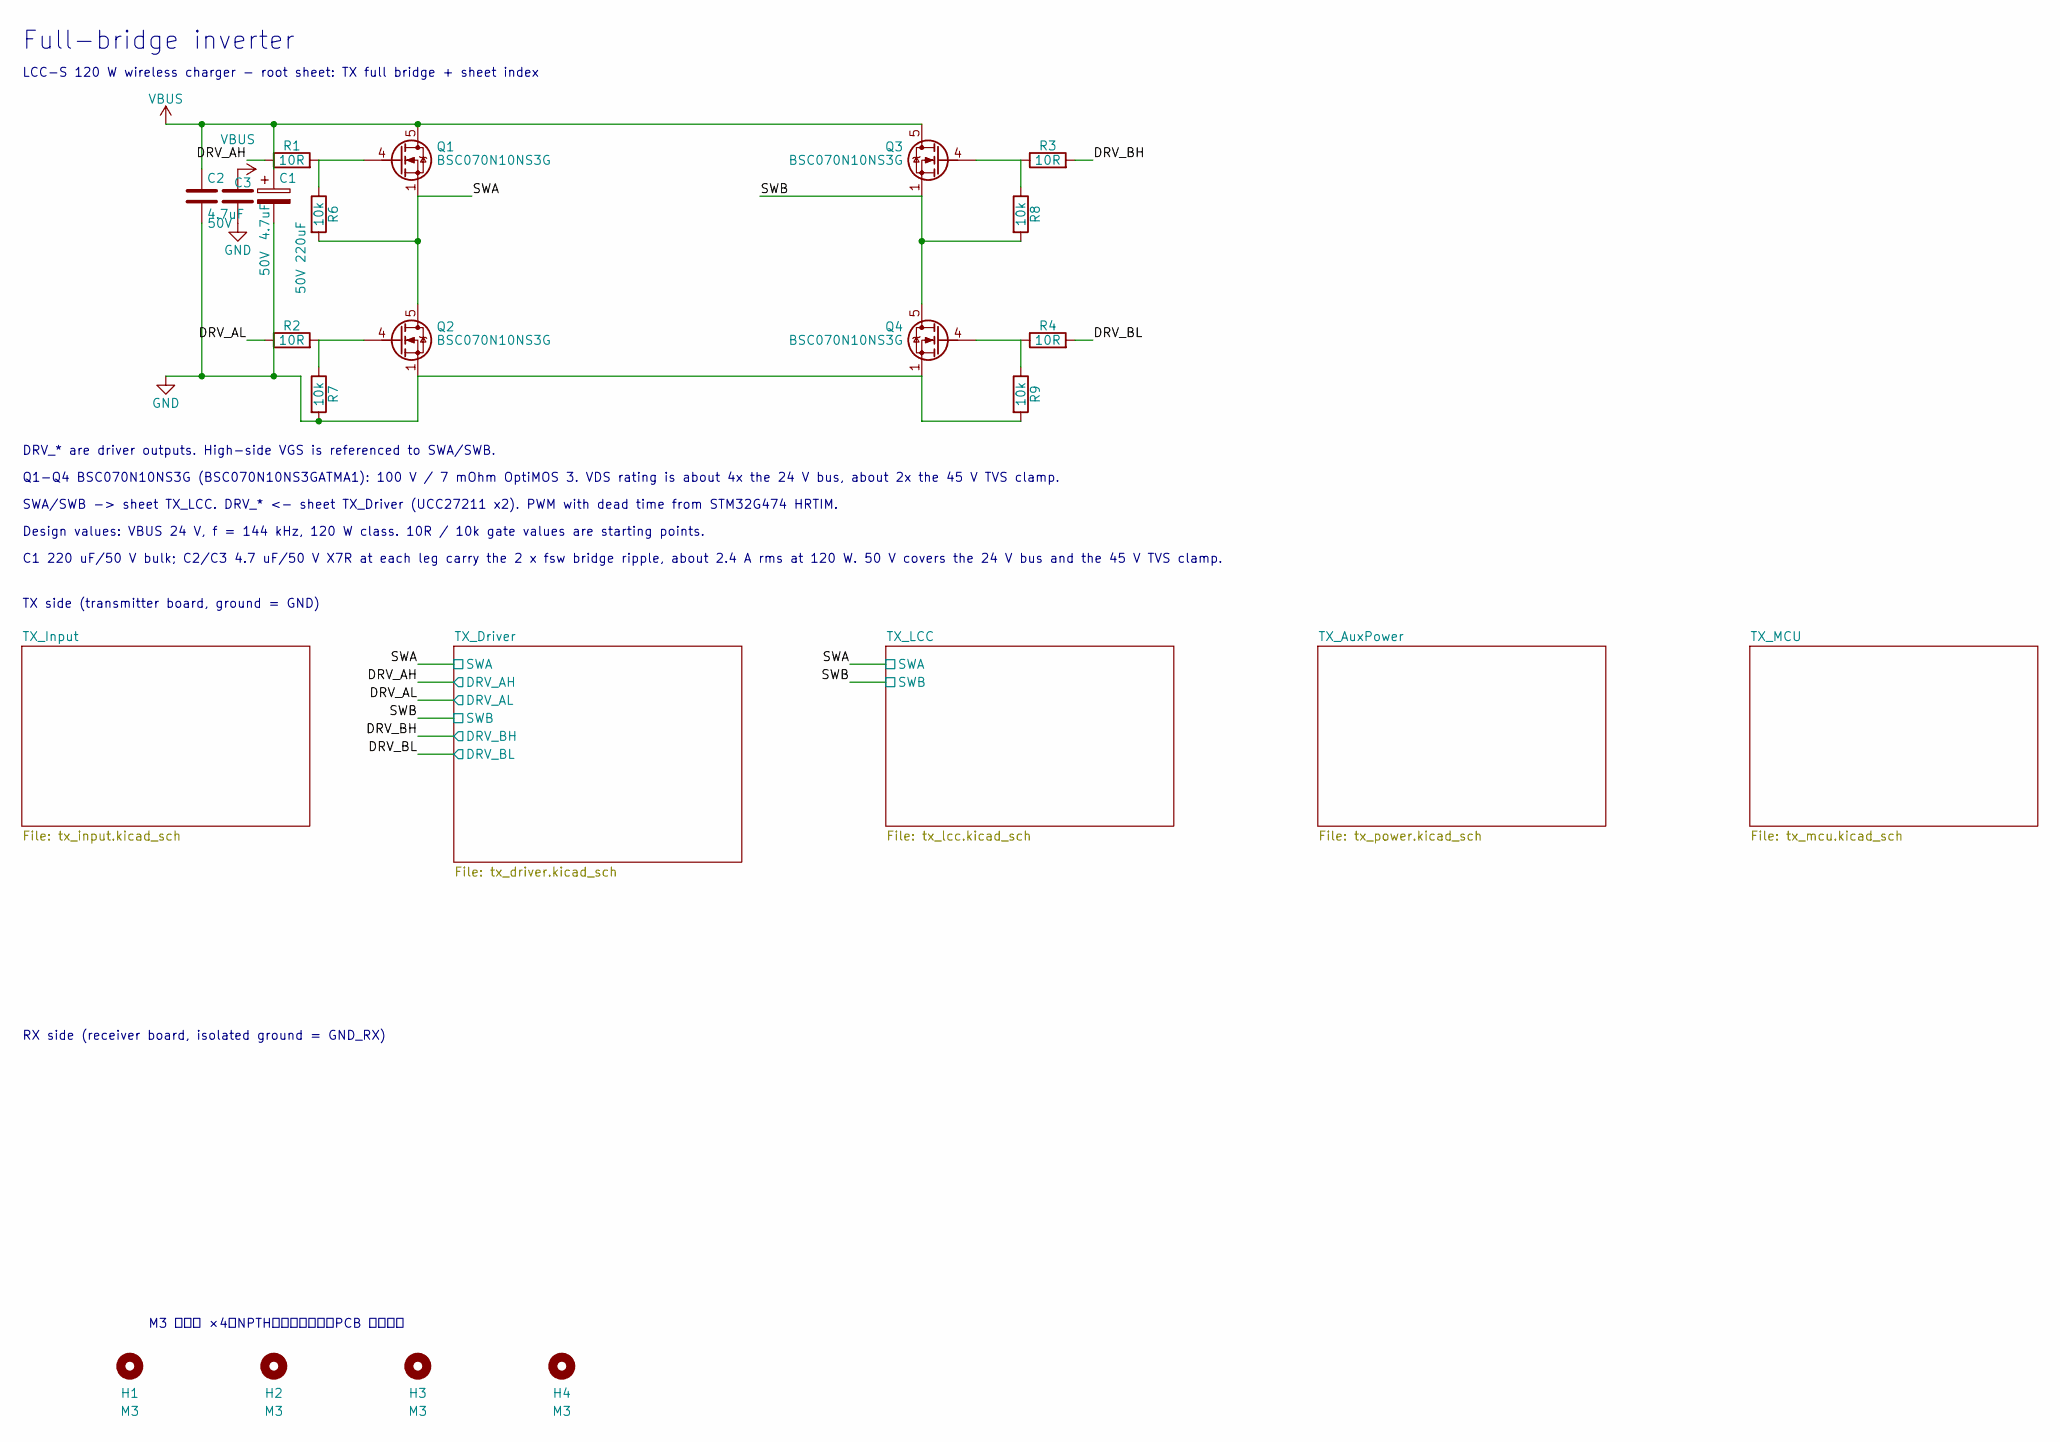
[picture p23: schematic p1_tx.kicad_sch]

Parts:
C1: 220uF; CP_Elec_10x10.5; Voltage 50V
C2, C3: 4.7uF; C_1210_3225Metric; Voltage 50V
H1, H2, H3, H4: M3; MountingHole_3.2mm_M3
Q1, Q2, Q3, Q4: BSC070N10NS3G; Infineon_PG-TDSON-8_6.15x5.15mm
R1, R2, R3, R4: 10R; R_0603_1608Metric
R6, R7, R8, R9: 10k; R_0603_1608Metric

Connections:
/DRV_AH: R1.1; also elsewhere on the board
/DRV_AL: R2.1; also elsewhere on the board
/DRV_BH: R3.2; also elsewhere on the board
/DRV_BL: R4.2; also elsewhere on the board
/SWA: Q1.1 (S), Q1.2 (S), Q1.3 (S), Q2.5 (D), R6.2; also elsewhere on the board
/SWB: Q3.1 (S), Q3.2 (S), Q3.3 (S), Q4.5 (D), R8.2; also elsewhere on the board
unnamed: Q1.4 (G), R1.2, R6.1
unnamed: Q2.4 (G), R2.2, R7.1
unnamed: Q3.4 (G), R3.1, R8.1
unnamed: Q4.4 (G), R4.1, R9.1

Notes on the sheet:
DRV_* are driver outputs. High-side VGS is referenced to SWA/SWB.
LCC-S 120 W wireless charger - root sheet: TX full bridge + sheet index
Q1-Q4 BSC070N10NS3G (BSC070N10NS3GATMA1): 100 V / 7 mOhm OptiMOS 3. VDS rating is about 4x the 24 V bus, about 2x the 45 V TVS clamp.
RX side (receiver board, isolated ground = GND_RX)
M3 安装孔 ×4（NPTH，板角各一个，PCB 上定位）
Design values: VBUS 24 V, f = 144 kHz, 120 W class. 10R / 10k gate values are starting points.
TX side (transmitter board, ground = GND)
C1 220 uF/50 V bulk; C2/C3 4.7 uF/50 V X7R at each leg carry the 2 x fsw bridge ripple, about 2.4 A rms at 120 W. 50 V covers the 24 V bus and the 45 V TVS clamp.
Full-bridge inverter
SWA/SWB -> sheet TX_LCC. DRV_* <- sheet TX_Driver (UCC27211 x2). PWM with dead time from STM32G474 HRTIM.

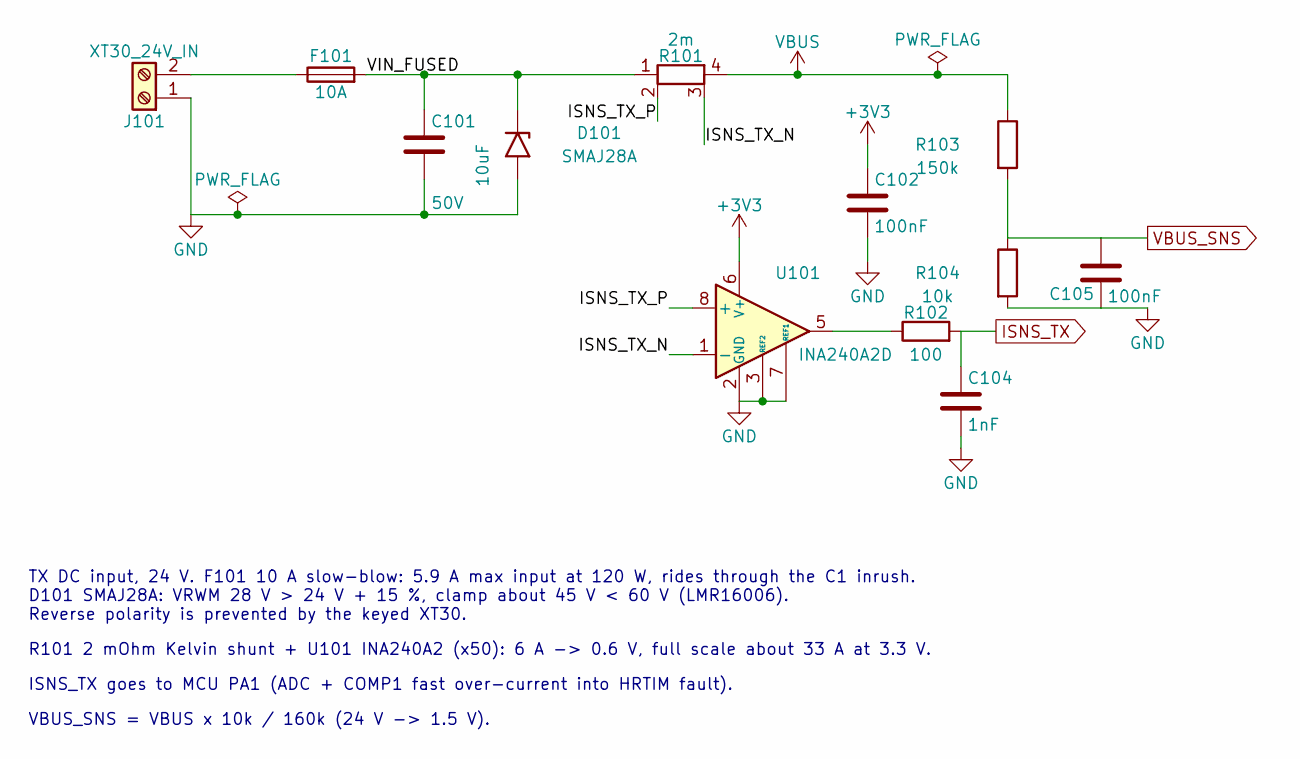
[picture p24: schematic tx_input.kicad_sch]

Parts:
C101: 10uF; C_1210_3225Metric; Voltage 50V
C102, C105: 100nF; C_0603_1608Metric
C104: 1nF; C_0603_1608Metric
D101: SMAJ28A; D_SMA
F101: 10A; Fuse_Littelfuse-NANO2-451_453
J101: XT30_24V_IN; AMASS_XT30PW-M_1x02_P2.50mm_Horizontal
R101: 2m; R_Shunt_Vishay_WSK2512_6332Metric_T1.19mm
R102: 100; R_0603_1608Metric
R103: 150k; R_0603_1608Metric
R104: 10k; R_0603_1608Metric
U101: INA240A2D; SOIC-8_3.9x4.9mm_P1.27mm

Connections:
+3V3: C102.1, U101.6 (V+); also elsewhere on the board
/TX_Input/ISNS_TX_N: R101.3, U101.1 (-)
/TX_Input/ISNS_TX_P: R101.2, U101.8 (+)
/TX_Input/VIN_FUSED: C101.1, D101.1 (A1), F101.2, R101.1
ISNS_TX: C104.1, R102.2; also elsewhere on the board
unnamed: F101.1, J101.2
unnamed: R102.1, U101.5
VBUS_SNS: C105.1, R103.2, R104.1; also elsewhere on the board

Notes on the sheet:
TX DC input, 24 V. F101 10 A slow-blow: 5.9 A max input at 120 W, rides through the C1 inrush. D101 SMAJ28A: VRWM 28 V > 24 V + 15 %, clamp about 45 V < 60 V (LMR16006). Reverse polarity is prevented by the keyed XT30.
R101 2 mOhm Kelvin shunt + U101 INA240A2 (x50): 6 A -> 0.6 V, full scale about 33 A at 3.3 V.
VBUS_SNS = VBUS x 10k / 160k (24 V -> 1.5 V).
ISNS_TX goes to MCU PA1 (ADC + COMP1 fast over-current into HRTIM fault).

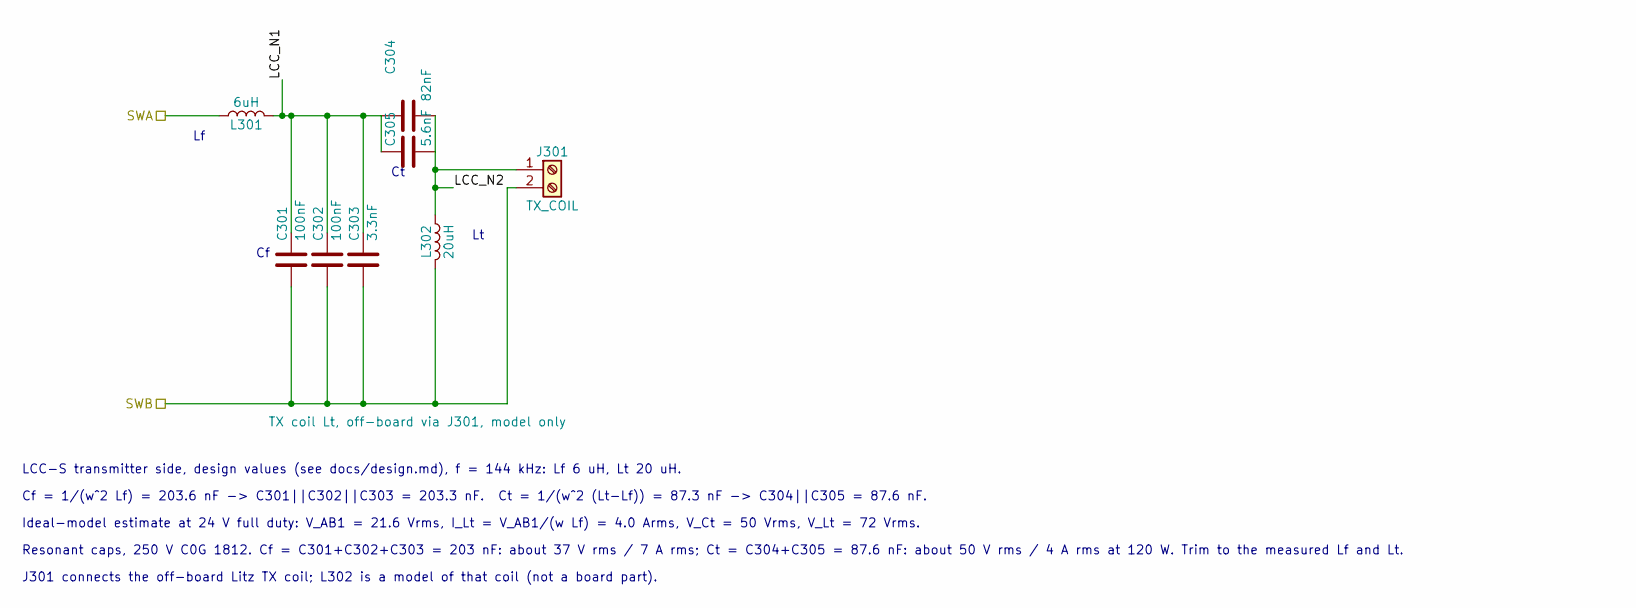
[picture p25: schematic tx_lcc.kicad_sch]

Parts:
C301, C302: 100nF; C_1812_4532Metric; Voltage 250V C0G
C303: 3.3nF; C_1812_4532Metric; Voltage 250V C0G
C304: 82nF; C_1812_4532Metric; Voltage 250V C0G
C305: 5.6nF; C_1812_4532Metric; Voltage 250V C0G
J301: TX_COIL; TerminalBlock_Phoenix_MKDS-1,5-2-5.08_1x02_P5.08mm_Horizont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
L301: 6uH; L_12x12mm_H8mm
L302: 20uH

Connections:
/SWA: L301.1; also elsewhere on the board
/SWB: C301.2, C302.2, C303.2, J301.2, L302.2; also elsewhere on the board
/TX_LCC/LCC_N1: C301.1, C302.1, C303.1, C304.1, C305.1, L301.2
/TX_LCC/LCC_N2: C304.2, C305.2, J301.1, L302.1

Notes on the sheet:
Ideal-model estimate at 24 V full duty: V_AB1 = 21.6 Vrms, I_Lt = V_AB1/(w Lf) = 4.0 Arms, V_Ct = 50 Vrms, V_Lt = 72 Vrms.
Resonant caps, 250 V C0G 1812. Cf = C301+C302+C303 = 203 nF: about 37 V rms / 7 A rms; Ct = C304+C305 = 87.6 nF: about 50 V rms / 4 A rms at 120 W. Trim to the measured Lf and Lt.
Cf = 1/(w^2 Lf) = 203.6 nF -> C301||C302||C303 = 203.3 nF. Ct = 1/(w^2 (Lt-Lf)) = 87.3 nF -> C304||C305 = 87.6 nF.
LCC-S transmitter side, design values (see docs/design.md), f = 144 kHz: Lf 6 uH, Lt 20 uH.
J301 connects the off-board Litz TX coil; L302 is a model of that coil (not a board part).

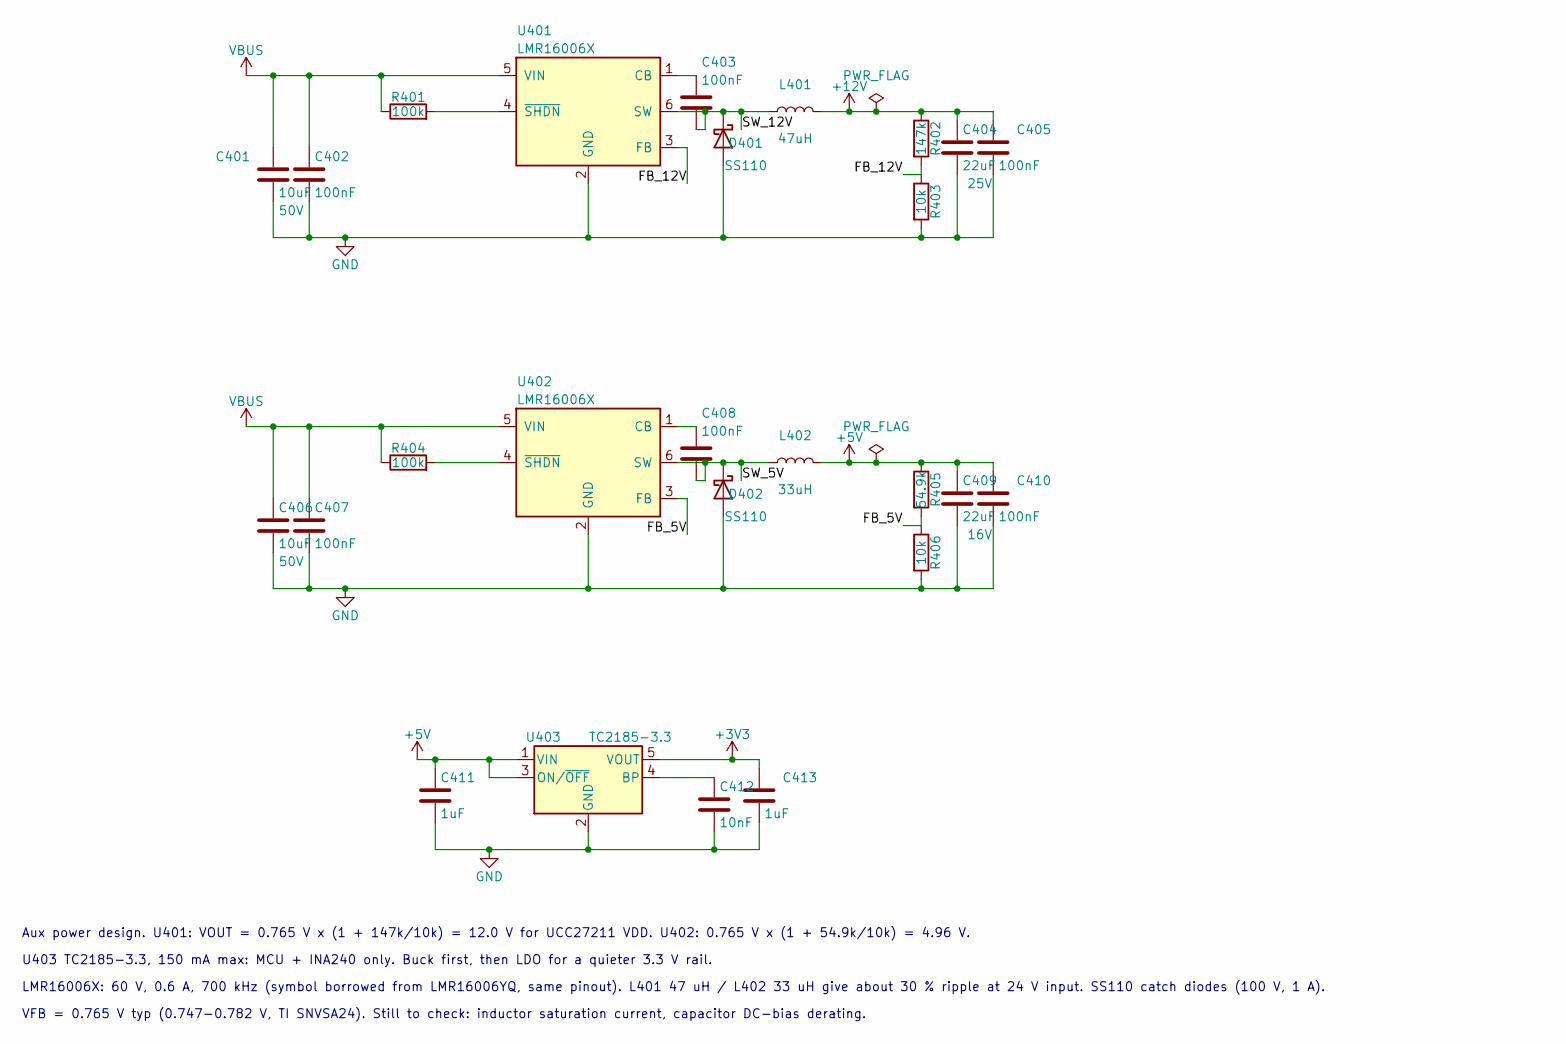
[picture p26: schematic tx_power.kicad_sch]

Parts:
C401, C406: 10uF; C_1210_3225Metric; Voltage 50V
C402, C403, C405, C407, C408, C410: 100nF; C_0603_1608Metric
C404: 22uF; C_1210_3225Metric; Voltage 25V
C409: 22uF; C_1210_3225Metric; Voltage 16V
C411, C413: 1uF; C_0603_1608Metric
C412: 10nF; C_0603_1608Metric
D401, D402: SS110; D_SMA
L401: 47uH; L_Taiyo-Yuden_NR-50xx
L402: 33uH; L_Taiyo-Yuden_NR-50xx
R401, R404: 100k; R_0603_1608Metric
R402: 147k; R_0603_1608Metric
R403, R406: 10k; R_0603_1608Metric
R405: 54.9k; R_0603_1608Metric
U401, U402: LMR16006X; SOT-23-6
U403: TC2185-3.3; SOT-23-5

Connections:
+3V3: C413.1, U403.5 (VOUT); also elsewhere on the board
/TX_AuxPower/FB_5V: R405.2, R406.1, U402.3 (FB)
/TX_AuxPower/FB_12V: R402.2, R403.1, U401.3 (FB)
/TX_AuxPower/SW_5V: C408.2, D402.1 (K), L402.1, U402.6 (SW)
/TX_AuxPower/SW_12V: C403.2, D401.1 (K), L401.1, U401.6 (SW)
unnamed: C403.1, U401.1 (CB)
unnamed: R401.2, U401.4 (~SHDN)
unnamed: C408.1, U402.1 (CB)
unnamed: R404.2, U402.4 (~SHDN)
unnamed: C412.1, U403.4 (BP)

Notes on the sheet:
U403 TC2185-3.3, 150 mA max: MCU + INA240 only. Buck first, then LDO for a quieter 3.3 V rail.
VFB = 0.765 V typ (0.747-0.782 V, TI SNVSA24). Still to check: inductor saturation current, capacitor DC-bias derating.
Aux power design. U401: VOUT = 0.765 V x (1 + 147k/10k) = 12.0 V for UCC27211 VDD. U402: 0.765 V x (1 + 54.9k/10k) = 4.96 V.
LMR16006X: 60 V, 0.6 A, 700 kHz (symbol borrowed from LMR16006YQ, same pinout). L401 47 uH / L402 33 uH give about 30 % ripple at 24 V input. SS110 catch diodes (100 V, 1 A).

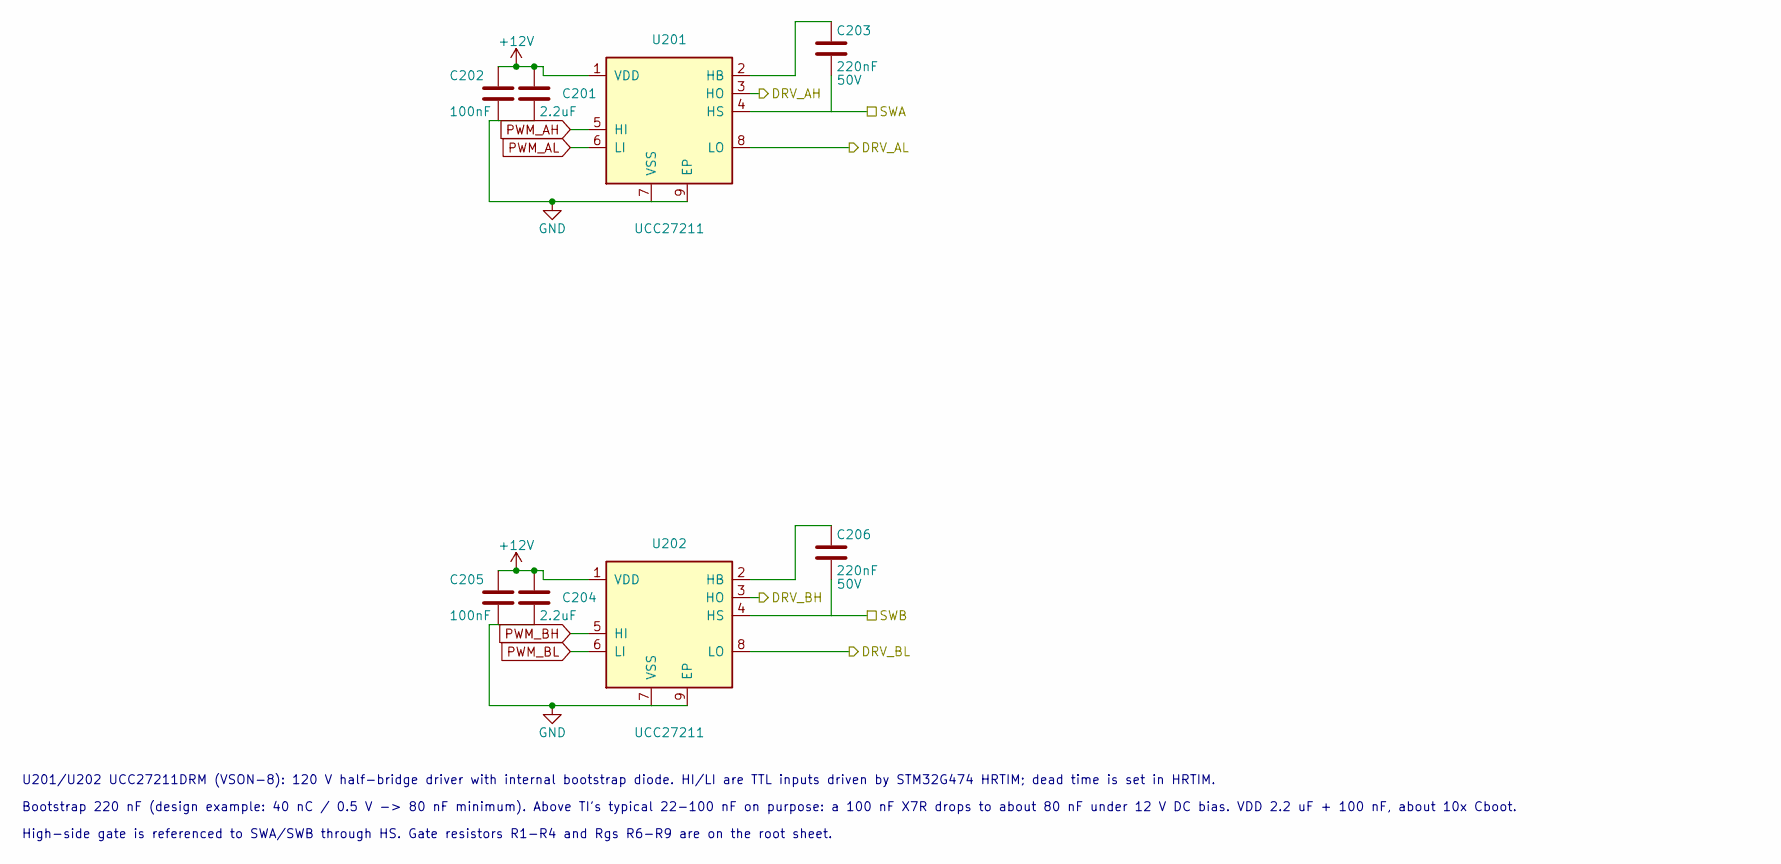
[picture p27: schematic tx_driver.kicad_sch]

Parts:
C201, C204: 2.2uF; C_0805_2012Metric; Voltage 25V
C202, C205: 100nF; C_0603_1608Metric
C203, C206: 220nF; C_0805_2012Metric; Voltage 50V
U201, U202: UCC27211; HVSON-8-1EP_4x4mm_P0.8mm_EP2.2x3.1mm

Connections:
/DRV_AH: U201.3 (HO); also elsewhere on the board
/DRV_AL: U201.8 (LO); also elsewhere on the board
/DRV_BH: U202.3 (HO); also elsewhere on the board
/DRV_BL: U202.8 (LO); also elsewhere on the board
/SWA: C203.2, U201.4 (HS); also elsewhere on the board
/SWB: C206.2, U202.4 (HS); also elsewhere on the board
unnamed: C203.1, U201.2 (HB)
unnamed: C206.1, U202.2 (HB)
PWM_AH: U201.5 (HI); also elsewhere on the board
PWM_AL: U201.6 (LI); also elsewhere on the board
PWM_BH: U202.5 (HI); also elsewhere on the board
PWM_BL: U202.6 (LI); also elsewhere on the board

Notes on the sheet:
High-side gate is referenced to SWA/SWB through HS. Gate resistors R1-R4 and Rgs R6-R9 are on the root sheet.
U201/U202 UCC27211DRM (VSON-8): 120 V half-bridge driver with internal bootstrap diode. HI/LI are TTL inputs driven by STM32G474 HRTIM; dead time is set in HRTIM.
Bootstrap 220 nF (design example: 40 nC / 0.5 V -> 80 nF minimum). Above TI's typical 22-100 nF on purpose: a 100 nF X7R drops to about 80 nF under 12 V DC bias. VDD 2.2 uF + 100 nF, about 10x Cboot.

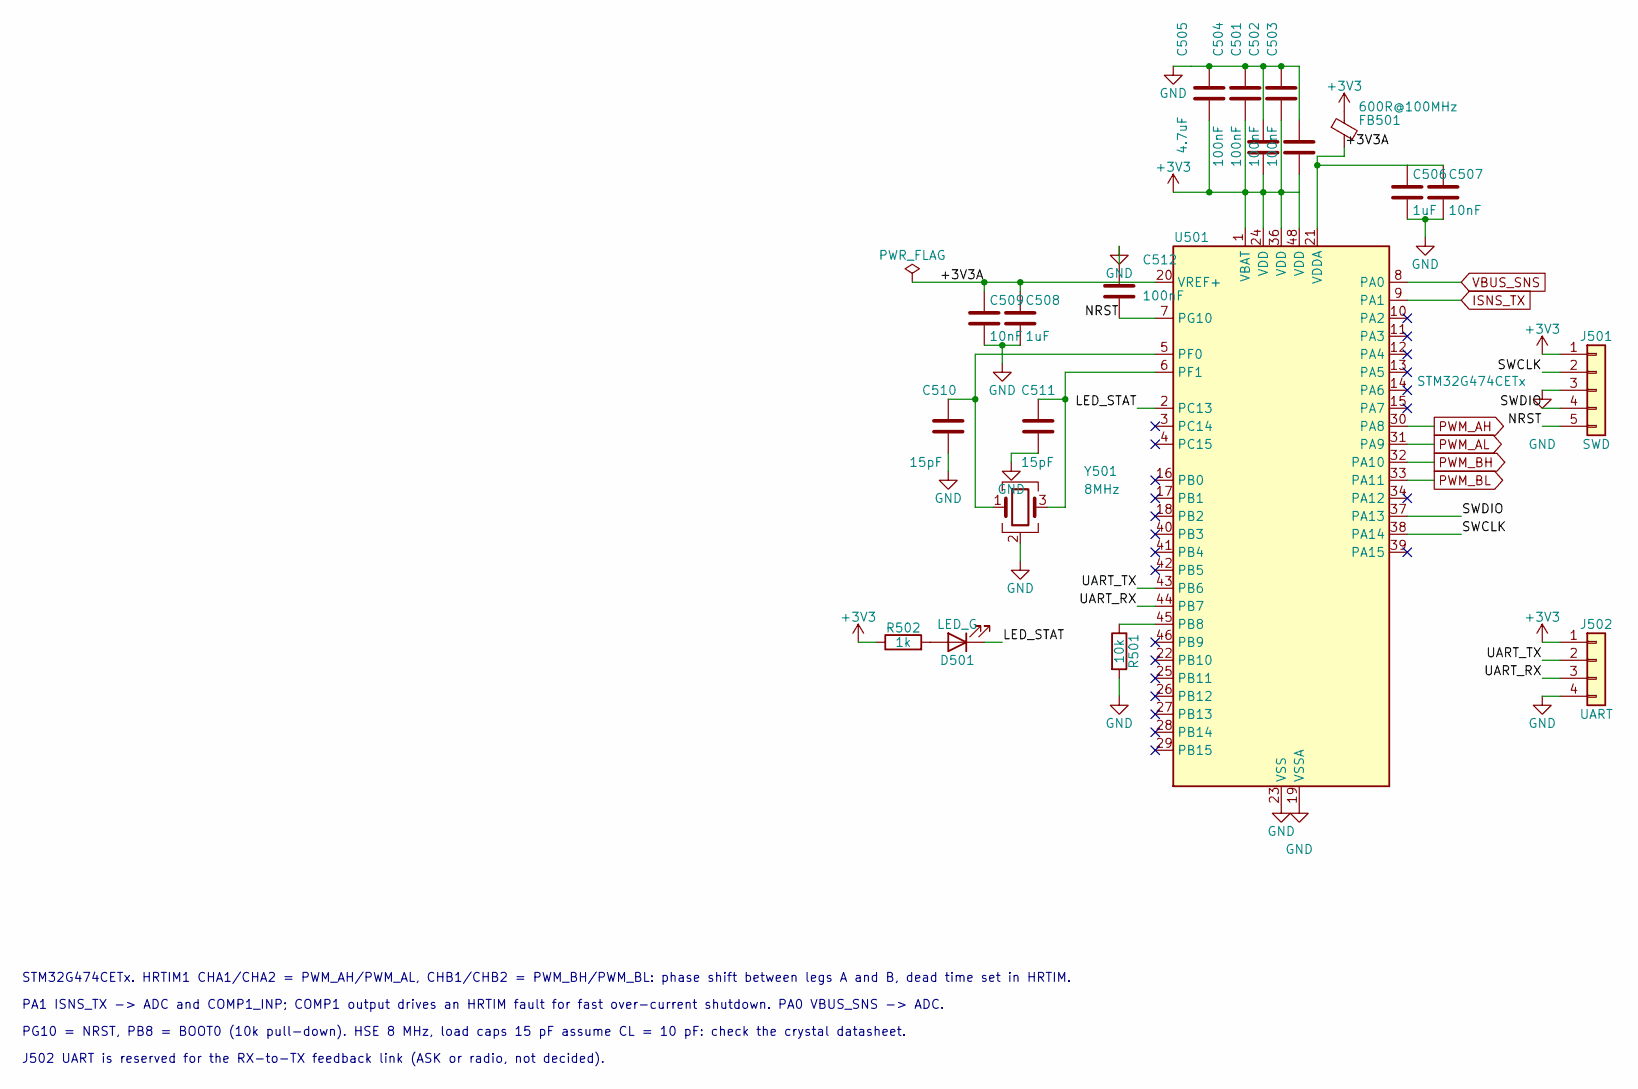
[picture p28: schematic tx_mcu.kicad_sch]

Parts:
C501, C502, C503, C504, C512: 100nF; C_0603_1608Metric
C505: 4.7uF; C_0805_2012Metric
C506, C508: 1uF; C_0603_1608Metric
C507, C509: 10nF; C_0603_1608Metric
C510, C511: 15pF; C_0603_1608Metric
D501: LED_G; LED_0603_1608Metric
FB501: 600R@100MHz; L_0603_1608Metric
J501: SWD; PinHeader_1x05_P2.54mm_Vertical
J502: UART; PinHeader_1x04_P2.54mm_Vertical
R501: 10k; R_0603_1608Metric
R502: 1k; R_0603_1608Metric
U501: STM32G474CETx; LQFP-48_7x7mm_P0.5mm
Y501: 8MHz; Crystal_SMD_3225-4Pin_3.2x2.5mm

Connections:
+3V3: C501.1, C502.1, C503.1, C504.1, C505.1, FB501.1, J501.1, J502.1, R502.1, U501.1 (VBAT), U501.24 (VDD), U501.36 (VDD), U501.48 (VDD); also elsewhere on the board
/TX_MCU/+3V3A: C506.1, C507.1, C508.1, C509.1, FB501.2, U501.20 (VREF+), U501.21 (VDDA)
/TX_MCU/LED_STAT: D501.1 (K), U501.2 (PC13)
/TX_MCU/NRST: C512.2, J501.5, U501.7 (PG10)
/TX_MCU/SWCLK: J501.2, U501.38 (PA14)
/TX_MCU/SWDIO: J501.4, U501.37 (PA13)
/TX_MCU/UART_RX: J502.3, U501.44 (PB7)
/TX_MCU/UART_TX: J502.2, U501.43 (PB6)
ISNS_TX: U501.9 (PA1); also elsewhere on the board
unnamed: D501.2 (A), R502.2
unnamed: R501.1, U501.45 (PB8)
unnamed: C510.1, U501.5 (PF0), Y501.1
unnamed: C511.1, U501.6 (PF1), Y501.3
PWM_AH: U501.30 (PA8); also elsewhere on the board
PWM_AL: U501.31 (PA9); also elsewhere on the board
PWM_BH: U501.32 (PA10); also elsewhere on the board
PWM_BL: U501.33 (PA11); also elsewhere on the board
VBUS_SNS: U501.8 (PA0); also elsewhere on the board

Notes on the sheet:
J502 UART is reserved for the RX-to-TX feedback link (ASK or radio, not decided).
PA1 ISNS_TX -> ADC and COMP1_INP; COMP1 output drives an HRTIM fault for fast over-current shutdown. PA0 VBUS_SNS -> ADC.
PG10 = NRST, PB8 = BOOT0 (10k pull-down). HSE 8 MHz, load caps 15 pF assume CL = 10 pF: check the crystal datasheet.
STM32G474CETx. HRTIM1 CHA1/CHA2 = PWM_AH/PWM_AL, CHB1/CHB2 = PWM_BH/PWM_BL: phase shift between legs A and B, dead time set in HRTIM.

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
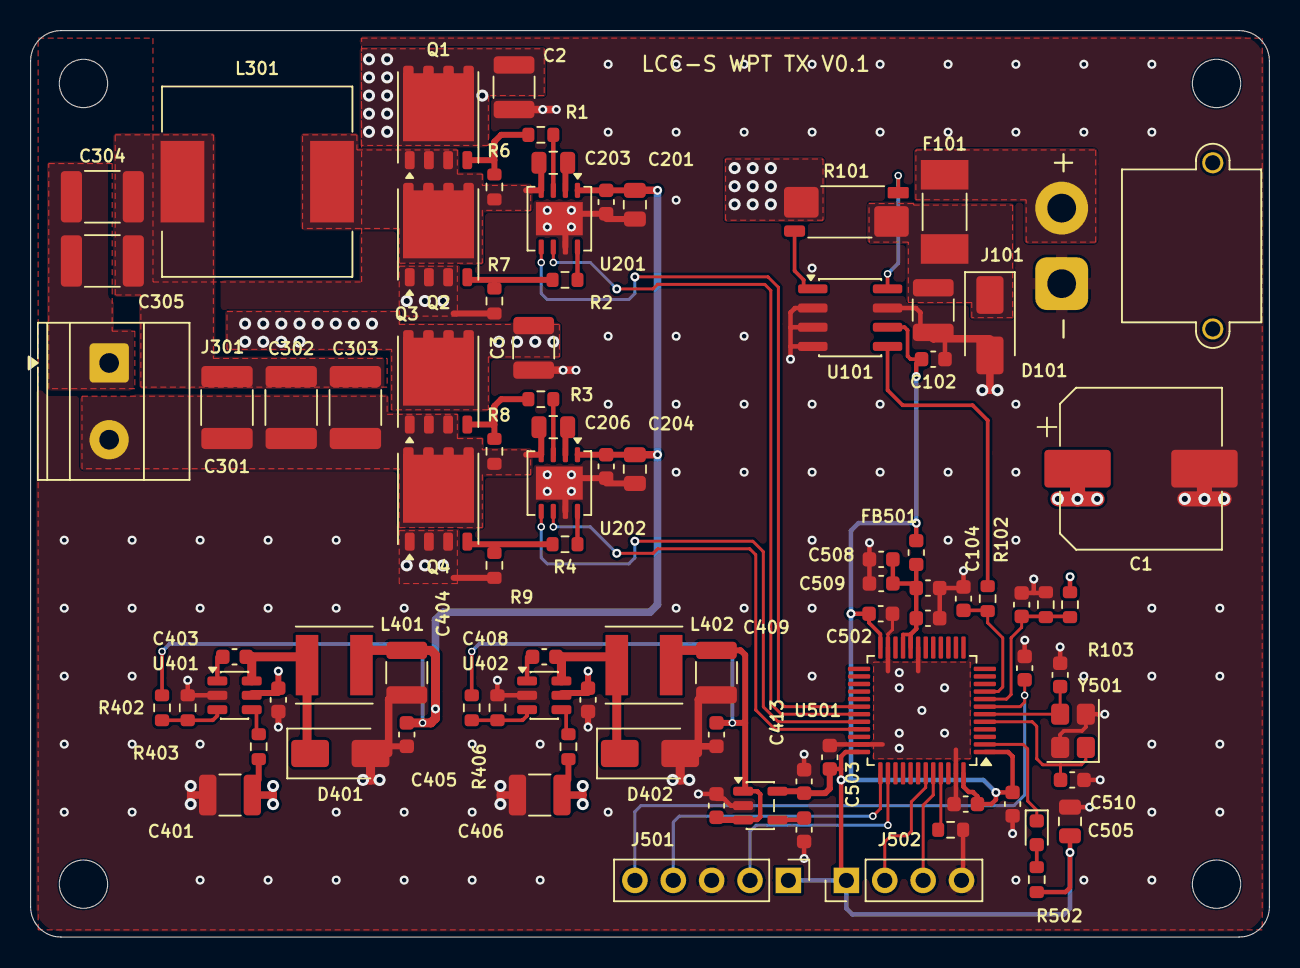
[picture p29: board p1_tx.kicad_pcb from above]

Board: 4 copper layers, 82.0 x 60.0 mm, 92 parts (0 on the bottom side), 50 nets.

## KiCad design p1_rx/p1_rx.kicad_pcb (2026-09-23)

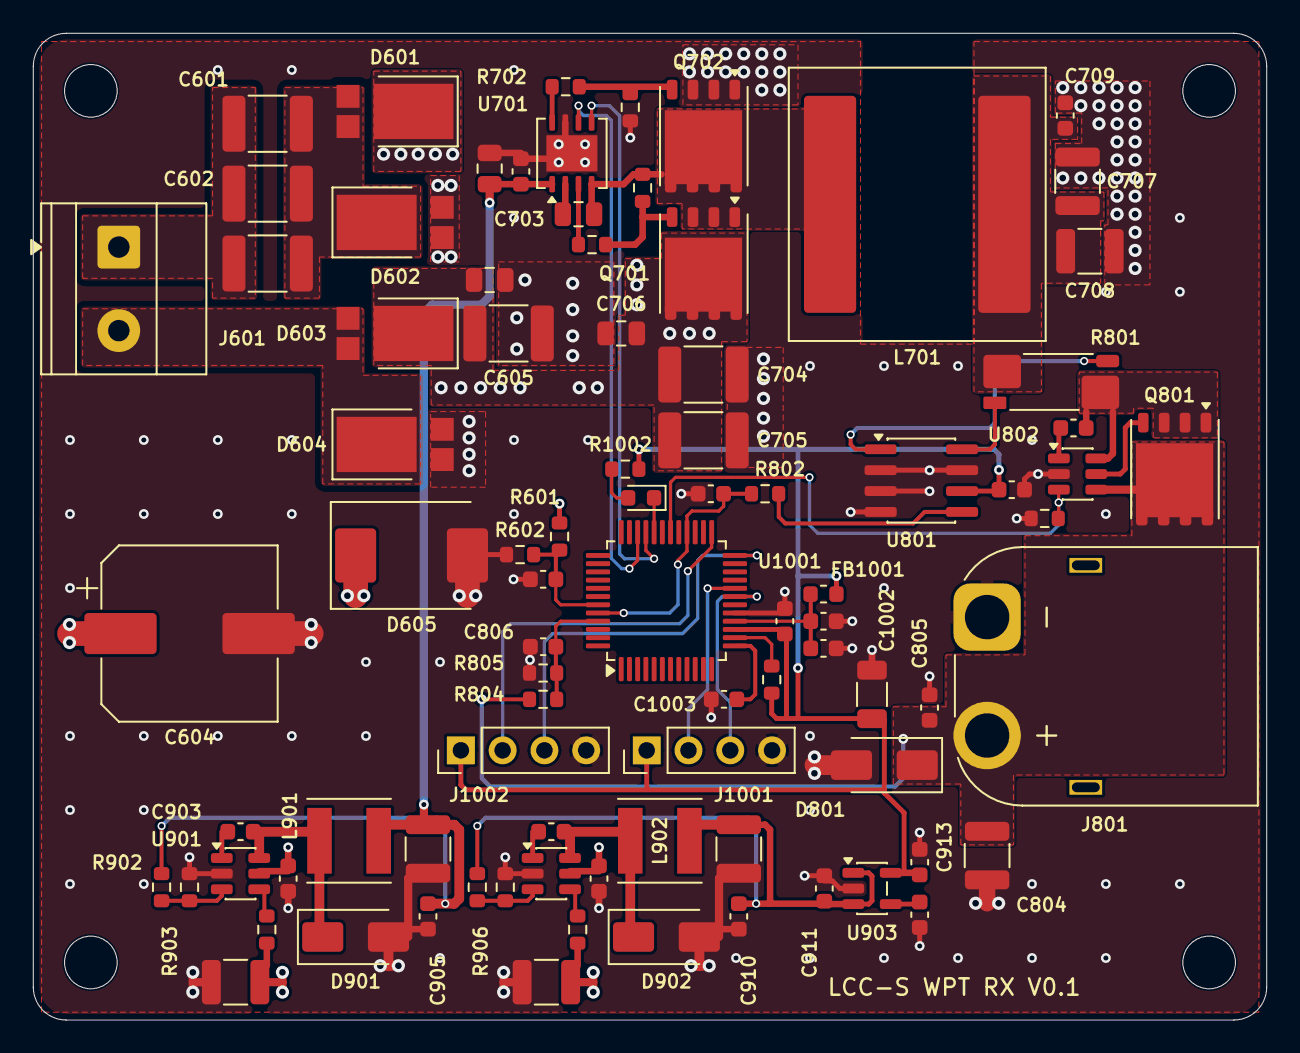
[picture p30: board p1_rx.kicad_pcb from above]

Board: 4 copper layers, 75.0 x 60.0 mm, 90 parts (0 on the bottom side), 46 nets.

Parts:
C601: 56nF; C_1812_4532Metric
C602: 4.7nF; C_1812_4532Metric
C603: 470pF; C_1812_4532Metric
C604: 100uF; CP_Elec_10x10.5
C605, C704, C705: 10uF; C_1812_4532Metric
C606, C706: 100nF; C_0805_2012Metric
C607, C702, C709, C801, C803, C805, C806, C902, C903, C905, C907, C908, C910, C1001, C1003, C1005: 100nF; C_0603_1608Metric
C701: 2.2uF; C_0805_2012Metric
C703: 220nF; C_0805_2012Metric
C707, C708, C804, C904, C909: 22uF; C_1210_3225Metric
C802: 1nF; C_0603_1608Metric
C901, C906: 4.7uF; C_1210_3225Metric
C911, C913, C1004: 1uF; C_0603_1608Metric
C912: 10nF; C_0603_1608Metric
C1002: 22uF; C_1206_3216Metric
D601, D602, D603, D604: SB2060L; D_PowerDI-5
D605: SMCJ33A; D_SMC
D801: SMAJ26A; D_SMA
D901, D902: SS110; D_SMA
D1001: LED_G; LED_0603_1608Metric
FB1001: 600R@100MHz; L_0603_1608Metric
H1, H2, H3, H4: M3; MountingHole_3.2mm_M3
J601: RX_COIL; TerminalBlock_Phoenix_MKDS-1,5-2-5.08_1x02_P5.08mm_Horizont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
J801: XT60_SUPERCAP; AMASS_XT60PW-M_1x02_P7.20mm_Horizontal
J1001: ISP; PinHeader_1x04_P2.54mm_Vertical
J1002: UART_LINK; PinHeader_1x04_P2.54mm_Vertical
L701: 15uH; L_Coilcraft_XAL1510-153
L901: 56uH; L_Taiyo-Yuden_NR-50xx
L902: 33uH; L_Taiyo-Yuden_NR-50xx
Q701, Q702, Q801: BSC070N10NS3G; Infineon_PG-TDSON-8_6.15x5.15mm
R601, R804: 150k; R_0603_1608Metric
R602, R703, R704, R805, R903, R906, R1001: 10k; R_0603_1608Metric
R701, R702: 10R; R_0603_1608Metric
R801: 2m; R_Shunt_Vishay_WSK2512_6332Metric_T1.19mm
R802: 100; R_0603_1608Metric
R803, R901, R904: 100k; R_0603_1608Metric
R902: 147k; R_0603_1608Metric
R905: 54.9k; R_0603_1608Metric
R1002: 1k; R_0603_1608Metric
U701: UCC27211; HVSON-8-1EP_4x4mm_P0.8mm_EP2.2x3.1mm
U801: INA240A2D; SOIC-8_3.9x4.9mm_P1.27mm
U802: LM74700; SOT-23-6
U901, U902: LMR16006X; SOT-23-6
U903: TC2185-3.3; SOT-23-5
U1001: STC32G12K128; LQFP-48_7x7mm_P0.5mm

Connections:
+3V3_RX: C801.1, C913.1, C1001.1, C1002.1, FB1001.1, J1001.1, J1002.1, R1001.1, R1002.1, U801.6, U903.5, U1001.15
+5V_RX: C909.1, C910.1, C911.1, L902.2, R905.1, U903.1, U903.3
+12V_RX: C701.1, C702.1, C904.1, C905.1, L901.2, R902.1, U701.1
/RX_AuxPower/FB_5V_RX: R905.2, R906.1, U902.3
/RX_AuxPower/FB_12V_RX: R902.2, R903.1, U901.3
/RX_AuxPower/SW_5V_RX: C908.2, D902.1, L902.1, U902.6
/RX_AuxPower/SW_12V_RX: C903.2, D901.1, L901.1, U901.6
/RX_Buck/BUCK_SW: C703.2, L701.1, Q701.1, Q701.2, Q701.3, Q702.5, R703.2, U701.4
/RX_CoilRect/RX_AC1: C601.2, C602.2, C603.2, D601.2, D602.1
/RX_CoilRect/RX_AC2: D603.2, D604.1, J601.2
/RX_CoilRect/RX_COIL1: C601.1, C602.1, C603.1, J601.1
/RX_MCU/ISP_RXD: J1001.3, U1001.19
/RX_MCU/ISP_TXD: J1001.2, U1001.20
/RX_MCU/LINK_RX: J1002.3, U1001.24
/RX_MCU/LINK_TX: J1002.2, U1001.25
/RX_MCU/VREF_RX: C1004.1, C1005.1, FB1001.2, U1001.16
/RX_Output/CHG_OUT: C803.2, Q801.1, Q801.2, Q801.3, R801.4, U802.6
/RX_Output/ISNS_CHG_N: R801.3, U801.1
/RX_Output/ISNS_CHG_P: R801.2, U801.8
BUCK_OUT: C707.1, C708.1, C709.1, L701.2, R801.1
CHG_EN: R803.1, U802.3, U1001.30
GND_RX: C604.2, C605.2, C606.2, C607.2, C701.2, C702.2, C704.2, C705.2, C706.2, C707.2, C708.2, C709.2, C801.2, C802.2, C804.2, C805.2, C806.2, C901.2, C902.2, C904.2, C905.2, C906.2, C907.2, C909.2, C910.2, C911.2, C912.2, C913.2, C1001.2, C1002.2, C1003.1, C1004.2, C1005.2, D602.2, D604.2, D605.2, D801.2, D901.2, D902.2, J801.1, J1001.4, J1002.4, Q702.1, Q702.2, Q702.3, R602.2, R704.2, R803.2, R805.2, R903.2, R906.2, U701.7, U701.9, U801.2, U801.3, U801.4, U801.7, U802.2, U901.2, U902.2, U903.2, U1001.17
ISNS_CHG: C802.1, R802.2, U1001.28, U1001.44
unnamed: D1001.2, R1002.2
unnamed: D1001.1, U1001.32
unnamed: Q701.4, R701.2, R703.1
unnamed: Q702.4, R702.2, R704.1
unnamed: Q801.4, U802.5
unnamed: R802.1, U801.5
unnamed: C703.1, U701.2
unnamed: R701.1, U701.3
unnamed: R702.1, U701.8
unnamed: C803.1, U802.1
unnamed: C903.1, U901.1
unnamed: R901.2, U901.4
unnamed: C908.1, U902.1
unnamed: R904.2, U902.4
unnamed: C912.1, U903.4
unnamed: R1001.2, U1001.14
unnamed: C1003.2, U1001.13
PWM_BUCK_H: U701.5, U1001.33
PWM_BUCK_L: U701.6, U1001.34
VRECT: C604.1, C605.1, C606.1, C704.1, C705.1, C706.1, C901.1, C902.1, C906.1, C907.1, D601.1, D603.1, D605.1, Q701.5, R601.1, R901.1, R904.1, U901.5, U902.5
VRECT_SNS: C607.1, R601.2, R602.1, U1001.43
VSCAP: C804.1, C805.1, D801.1, J801.2, Q801.5, R804.1, U802.4
VSCAP_SNS: C806.1, R804.2, R805.1, U1001.45
